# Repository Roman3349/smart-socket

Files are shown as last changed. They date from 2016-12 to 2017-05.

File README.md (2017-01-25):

# Smart socket



The IQRF project to switching mains voltage.

## License
This project is licensed under the GPLv3 license:

 > Copyright (C) 2017 Roman Ondráček
 >
 > This program is free software: you can redistribute it and/or modify
 > it under the terms of the GNU General Public License as published by
 > the Free Software Foundation, either version 3 of the License, or
 > (at your option) any later version.
 > 
 > This program is distributed in the hope that it will be useful,
 > but WITHOUT ANY WARRANTY; without even the implied warranty of
 > MERCHANTABILITY or FITNESS FOR A PARTICULAR PURPOSE.  See the
 > GNU General Public License for more details.
 >
 > You should have received a copy of the GNU General Public License
 > along with this program.  If not, see <http://www.gnu.org/licenses/>.

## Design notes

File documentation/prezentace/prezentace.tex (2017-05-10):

\documentclass[11pt]{beamer}
% Nastavení znakové sady Unicode
\usepackage{cmap}
\usetheme{Madrid}
\usepackage[utf8]{inputenc}
\usepackage[czech]{babel}
\usepackage[T1]{fontenc}
\usepackage{graphicx}
\usepackage{url}
\usepackage{hyperref}
\author[Roman Ondráček]{Roman Ondráček (Gymnázium Boskovice)}
\title[Dálkové ovládání domácích spotřebičů]{Dálkové ovládání domácích spotřebičů mobilním telefonem}
\setbeamercovered{transparent}
%\setbeamertemplate{navigation symbols}{}
\titlegraphic{}
\institute[]{Školitel: prof. Ing. Václav Říčný, CSc. (FEKT VUT)}
\date{\today}
%\subject{}
\begin{document}

\begin{frame}
\titlepage
\end{frame}

\begin{frame}{Obsah}
\tableofcontents
\end{frame}

\section{Co bylo cílem projektu}

\begin{frame}{Co bylo cílem projektu}
V~posledních létech je ve středu pozornosti tzv. Internet věcí a chytrá domácnost. \\[4mm]
Cílem projektu bylo navrhnout a sestavit chytrou zásuvku, která se ovládá pomocí SMS a která může spínat odporovou zátěž až 10~A.
\end{frame}

\section{Použité technologie}

\begin{frame}{Použité technologie}
  \begin{exampleblock}{Brána}
    \begin{itemize}
      \item Raspberry Pi 2
      \item Raspbian (Debian)
      \item Skriptovací jazyk Python 3
      \item USB GSM modem
      \item Bezdrátový modul IQRF DCTR-72DAT
      \item IQRF OS 3.08, IQRF DPA 2.x
    \end{itemize}
  \end{exampleblock}
  \begin{alertblock}{Chytrá zásuvka}
    \begin{itemize}
      \item Bezdrátový modul IQRF DCTR-72DAT
      \item IQRF OS 3.08, IQRF DPA 2.x
      \item Programovací jazyk C
    \end{itemize}
  \end{alertblock}
\end{frame}

\subsection{Bezdrátový modul IQRF}

\begin{frame}{Bezdrátový modul IQRF}
  Použil jsem bezdrátový modul IQRF DCTR-72DAT, který vyvíjí česká firma MICRORISC s.r.o., která sídlí v Jičíně.
  \begin{exampleblock}{Výhody}
    \begin{itemize}
      \item Malé rozměry.
      \item Zabezpečený přenos dat.
      \item Dobrá technická podpora.
      \item SDK pro mnoho platforem.
      \item V IQRF OS 4.0 je provoz šifrován pomocí šifry AES-128.
    \end{itemize}
  \end{exampleblock}
  \begin{alertblock}{Nevýhody}
    \begin{itemize}
      \item Vyšší cena.
    \end{itemize}
  \end{alertblock}
\end{frame}

\subsection{Komunikace}

\begin{frame}{Blokové schéma komunikace}
  \begin{center}
    
  \end{center}
\end{frame}

%\section{Bloková schémata}
%
%\begin{frame}{Bloková schémata}
%  \begin{center}
%    \minipage{0.50\textwidth}
%      \begin{figure}
%        \includegraphics[width = \textwidth]{../img/blokove-schema/brana.pdf}
%        \caption{Brána}
%      \end{figure}
%    \endminipage
%    \minipage{0.50\textwidth}
%      \begin{figure}
%        \includegraphics[width = \textwidth]{../img/blokove-schema/zasuvka.pdf}
%        \caption{Chytrá zásuvka}
%      \end{figure}
%    \endminipage
%  \end{center}
%\end{frame}

\section{Fotografie}

\begin{frame}{Fotografie}
  \begin{center}
    \minipage{0.50\textwidth}
      \begin{figure}
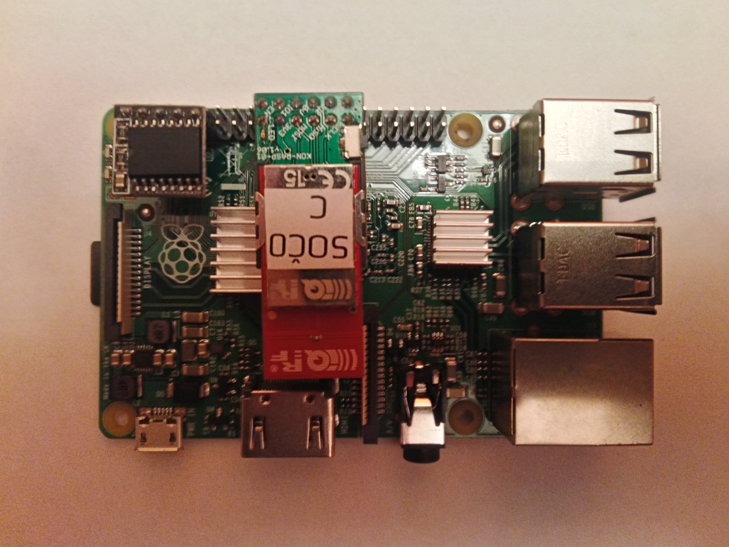
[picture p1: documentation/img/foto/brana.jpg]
        
        \caption{Brána}
      \end{figure}
    \endminipage
    \minipage{0.50\textwidth}
      \begin{figure}
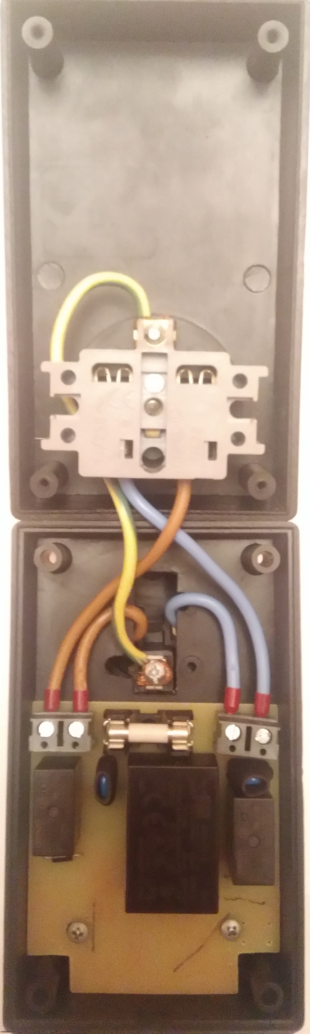
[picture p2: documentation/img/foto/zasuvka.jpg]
        
        \caption{Chytrá zásuvka}
      \end{figure}
    \endminipage
  \end{center}
\end{frame}

\section{Výhody a nevýhody řešení}

\begin{frame}{Výhody a nevýhody řešení}
  \begin{exampleblock}{Výhody}
    \begin{itemize}
      \item Projekt je open-source a je vytvořen pomocí open-source nebo freeware nástrojů.
      \item Chytrá zásuvka je provozně bezpečnější než většina konkurenčních zařízení, protože spíná obě zdířky zásuvky.
      \item Díky univerzálnosti a stavebnicovému řešení lze systém dobře rozšiřovat i o další funkce.
    \end{itemize}
  \end{exampleblock}
  \begin{alertblock}{Nevýhody}
    \begin{itemize}
      \item Vyšší cena.
    \end{itemize}
  \end{alertblock}
\end{frame}

\section{Živá ukázka}
\begin{frame}{Živá ukázka}
  \begin{center}
    \huge{\textit{Pravděpodobně} živá ukázka} \\
    \vspace{8mm}
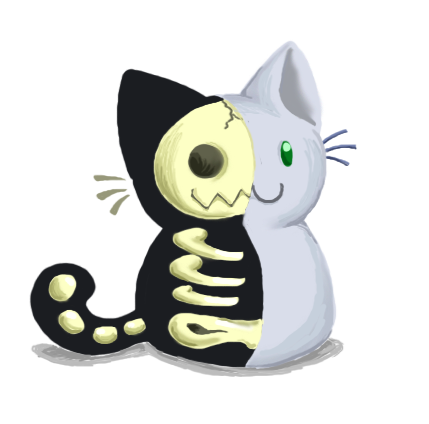
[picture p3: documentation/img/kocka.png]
    
    \vspace{8mm}
  \end{center}
  \small{Autor obrázku: Ketrina Yim (draguunthor.deviantart.com)}
\end{frame}

\section{Cíle do budoucna}

\begin{frame}{Cíle do budoucna}
  \begin{itemize}
    \item Doplnění měření spotřeby připojeného spotřebiče.
    \item Doplnění senzorů (např. pro měření teploty, vlhkosti).
    \item Doplnění možnosti ovládat zařízení přes Internet.
    \item Vytvoření mobilní aplikace pro Android, která by zjednodušila ovládání.
  \end{itemize}
\end{frame}

\begin{frame}
  \begin{center}
    \begin{huge}
    Děkuji za pozornost. \\[8mm]
    \end{huge}
    \large{Dotazy?}\\[16mm]
    \textbf{Zdrojové kódy:} \\
    \url{https://github.com/Roman3349/rpi-gw} \\
    \url{https://github.com/Roman3349/smart-socket} \\[16mm]
  \end{center}
  Zdroje obrázků:
  \begin{itemize}
    \item[] \hspace{-8mm} \tiny{\textbf{Schrödingerova kočka:} \url{http://draguunthor.deviantart.com/art/Schrodinger-s-Cat-163302750}}
  \end{itemize}
\end{frame}

\end{document}

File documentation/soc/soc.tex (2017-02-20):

\documentclass[12pt,a4paper,oneside]{article}
% Nastavení znakové sady Unicode
\usepackage{cmap}
\usepackage[a4paper,left=35mm,right=30mm,top=30mm,bottom=30mm]{geometry}
\usepackage[czech]{babel}
\usepackage[utf8]{inputenc}
\usepackage[T1]{fontenc}
\usepackage[dvipsnames]{xcolor}
\usepackage{float}
\usepackage{graphicx}
\usepackage{hyperref}
\usepackage{index}
\usepackage{listings}
\usepackage{url}
\usepackage{enumitem}
\input{yaml.tex}
\setlist{nolistsep}
\author{Roman Ondráček}
\title{Dálkové ovládání domácích spotřebičů mobilním telefonem}
% Vytvoření seznamu použitých zkratek
\newindex{zkr}{zdx}{znd}{Seznam použitých zkratek}
\lstset{
  inputencoding=utf8
}
\begin{document}
% Řádkování 1,5
\renewcommand{\baselinestretch}{1.5}
% Vynechání číslování
\pagestyle{empty}
\begin{center}
\large \textbf{STŘEDOŠKOLSKÁ ODBORNÁ ČINNOST} \\

\vspace{48mm}
% Český název
\huge \textbf{Dálkové ovládání domácích spotřebičů mobilním telefonem} \\

\vspace{64mm}
\end{center}

\begin{tabbing}
% Nastavení zarážek
\hspace{4mm} \= \hspace{24mm} \= \kill
\> \large \textbf{Autor:}  \> \large{Roman Ondráček}                                    \\[4mm]
\> \large \textbf{Škola:}  \> \large{Gymnázium Boskovice, příspěvková organizace}       \\[4mm]
\> \large \textbf{Kraj:}   \> \large{Jihomoravský}                                      \\[4mm]
\> \large \textbf{Obor:}   \> \large{10. Elektrotechnika, elektronika a telekomunikace} \\[24mm]
\> \large \textbf{Boskovice 2017}
\end{tabbing}

\newpage
% Zakázání číslování
\pagestyle{empty}
\begin{center}
\large \textbf{STŘEDOŠKOLSKÁ ODBORNÁ ČINNOST} \\

\vspace{48mm}
% Český název
\huge \textbf{Dálkové ovládání domácích spotřebičů mobilním telefonem} \\
\vspace{24mm}
% Anglický název
\huge \textbf{The remote control of home appliances via a mobile phone} \\

\vspace{24mm}
\end{center}

\begin{tabbing}
% Nastavení zarážek
\hspace{4mm} \= \hspace{24mm} \= \kill
\> \large \textbf{Autor:}     \> \large{Roman Ondráček}                                    \\[4mm]
\> \large \textbf{Škola:}     \> \large{Gymnázium Boskovice, příspěvková organizace}       \\[4mm]
\> \large \textbf{Kraj:}      \> \large{Jihomoravský}                                      \\[4mm]
\> \large \textbf{Školitel:}  \> \large{prof. Ing. Václav Říčný, CSc.}                     \\[4mm]
\> \large \textbf{Obor:}      \> \large{10. Elektrotechnika, elektronika a telekomunikace} \\[16mm]
\> \large \textbf{Boskovice 2017}
\end{tabbing}

\normalsize

\newpage

~ \vspace{128mm}

\section*{Prohlášení}

Prohlašuji, že svou práci na téma Dálkové ovládání domácích spotřebičů mobilním telefonem jsem vypracoval samostatně pod vedením prof. Ing. Václava Říčného, CSc. a s~použitím odborné literatury a dalších informačních zdrojů, které jsou všechny citovány v~práci a uvedeny v~seznamu literatury na konci práce. \\
Dále prohlašuji, že tištěná i elektronická verze práce SOČ jsou shodné a nemám závažný důvod proti zpřístupňování této práce v~souladu se zákonem č.~121/2000 Sb., o~právu autorském, o~právech souvisejících s~právem autorským a změně některých zákonů (autorský zákon) v~platném změní. \\[8mm]
V~Boskovicích dne \today \hspace{24mm} Podpis:

\newpage

~ \vspace{110mm}

\section*{Poděkování}

Děkuji svému školiteli prof. Ing. Václavu Říčnému CSc. za obětavou pomoc a podnětné připomínky, které mi během práce poskytoval. \\
Tato práce byla provedena za finanční podpory Jihomoravského kraje.

\vspace{8mm}
% Loga
\begin{figure}[!htb]
\minipage{0.50\textwidth}
   \\[8mm]
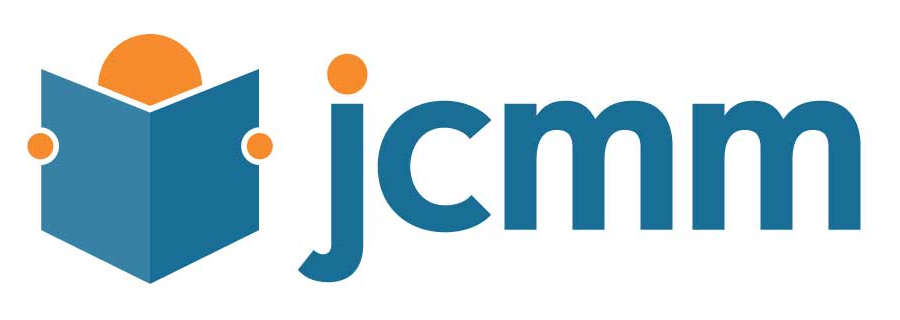
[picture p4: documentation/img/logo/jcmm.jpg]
  
\endminipage
\minipage{0.50\textwidth}
  
\endminipage
\end{figure}

\newpage

\section*{Anotace}

Cílem této práce je navrhnout a sestavit chytrou zásuvku, která se ovládá pomocí SMS a která může spínat odporovou zátěž až 10~A. Součástí mé práce je technická dokumentace výrobku, popis postupu výroby a samotný výrobek.

\subsection*{Klíčová slova}

GSM; SMS; IQRF; relé

\section*{Annotation}

The goal of this work is to design and build a smart power socket, which is controlled by a text message and which can switch resistive loads up to current 10~A. My work includes technical documentation, a description of the manufacturing process and the product itself.

\subsection*{Keywords}

GSM; text message; IQRF; relay

\newpage

% Nastavení číslování od Obsahu
\setcounter{page}{1}

\tableofcontents

\newpage

% Povolení číslování
\pagestyle{plain}

\section*{Úvod}

\addcontentsline{toc}{section}{Úvod}

V~posledních létech je ve středu pozornosti tzv. Internet věcí (IoT\index[zkr]{IoT!Internet of things|textit}) a chytrá domácnost. Na trhu jsou nabízeny chytré zásuvky, které však obvykle ovládány na kratší vzdálenosti a nenabízejí možnost pohodlně a bezpečně je ovládat vzdáleně pomocí mobilního telefonu. \\

Obvykle jsou tyto chytré zásuvky ovládány pomocí komunikace WiFi, která používá kmitočtové pásmo 2,4 GHz. Tato frekvence je hlavně ve městech hodně zarušená, protože se používá i pro přenosy jiných dat\cite{wiki/ism-band}. A proto většinou tyto chytré zásuvky lze ovládat pouze v~místní síti (LAN\index[zkr]{LAN!Local area network|textit}). Tento projekt má tedy umožnit ovládat tyto zásuvky (a tedy i elektrické spotřebiče v~nich zapojené) z~libovolné vzdálenosti. Navržený systém dálkového ovládání pomocí mobilního telefonu by měl, kromě vlastního ovládání, zabezpečit i přenos informace uživateli o~aktuálním stavu zásuvky. Cílem projektu je tedy návrh takové dálkově ovládané chytré zásuvky, její realizace a ověření funkčního vzorku. \\

Většina chytrých zásuvek obsahuje pouze jedno relé\cite{teardown-wemo-switch}, protože musí se povinně spínat fáze (spínání nulového vodiče je nepovinné). To přináší problém, protože například ve Francii, kde se stejně jako v~České republice použita zásuvka typu E\cite{zasuvka-typ-e}, je zdířka fáze umístěna vpravo nikoliv vlevo jako v~České republice\cite{faze-vlevo-nebo-vpravo}. Proto navržené řešení obsahuje i druhé relé pro spínání nulového vodiče. \\

Pro řešení zadání projektu jsem se rozhodl použít technologii IQRF. Je to technologie vyvinutá českou firmou Microrisc s.r.o., která se poměrně často používá ve světě internetu věcí a jiných systémů pro bezdrátový přenos malých objemů dat. Firma dává k~dispozici relativně malé moduly, které je možno integrovat do konkrétních zákaznických řešení.

\newpage

\section{Návrh hardware}

\subsection{Chytrá zásuvka}

Chytrá zásuvka je napájena ze sítě pomocí modulového spínaného zdroje do desky plošných spojů MEAN WELL IRM-02-5, který má výstupní napětí 5~V a maximální výstupní proud je 400~mA. \\

Chytrá zásuvka je řízena bezdrátovým modulem IQRF DCTR-72DAT, který spíná SMD\index[zkr]{SMD!Surface-mounted device|textit} unipolární tranzistory N-MOSFET\index[zkr]{N-MOSFET!N-Channel metal–oxide–semiconductor field-effect transistor|textit} BSS138. Ty spínají které spínají cívky dvou relé (jedno je použito pro spínání fáze a druhé relé je použito pro spínání nulového vodiče) OMRON G5Q-1A4-EU. \\

Při rozepnutí proudu v~cívce relé vzniká vlivem její indukčnosti napěťová špička, která může zničit spínací tranzistor. Proražení tranzistoru lze zabránit diodou paralelně zapojenou k~relé, která při rozepnutí relé uzavře obvod kolem indukčnosti. Použil jsem usměrňovací diodu 1N4007. Abych zabránil jiskření na kontaktech relé, jsem použil varistor MOV\index[zkr]{MOV!Metal Oxide Varistor|textit} SR PASSIVES VAR10-250.

\newpage

\subsubsection{Bezdrátový modul IQRF DCTR-72DAT}

V~chytré zásuvce jsem použil bezdrátový modul IQRF DCTR-72DAT, který rovněž vyrábí česká firma MICRORISC s.r.o., která sídlí v~Jičíně. Plošný spoj modulu má podobné rozměry jako SIM\index[zkr]{SIM!Subscriber identity module|textit} karta, proto je pro jeho připojení s~deskou plošných spojů použit konektor pro SIM karty. \\

\begin{figure}[H]
\centering
\label{fig:iqrf/fotka}
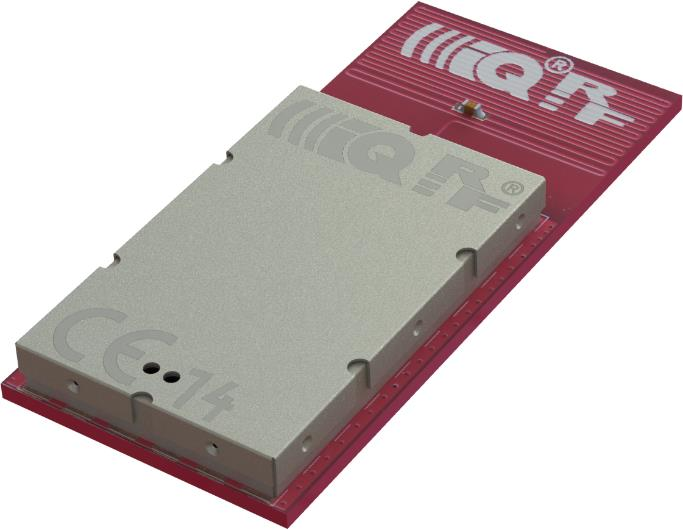
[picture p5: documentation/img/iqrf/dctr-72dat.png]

\caption{Fotografie bezdrátového modulu}
\end{figure}

Modul může vysílat na bezlicenčních pásmech 916~MHz, která je určené pro Ameriku, a 868~MHz, určené pro zbytek světa. Vysílací výkon modulu je 12,5~mW, používá GFSK\index[zkr]{GFSK!Gaussian frequency-shift keying|textit} modulaci. Modul má integrovanou anténu na svém plošném spoji. \\

Pro komunikaci používá tzv. mesh neboli smíšenou topologii. Ta má výhody v~robustnosti a v~absenci centrálního prvku. Její nevýhodou je naopak potřebná ochrana proti zacyklení a nutnost směrování provozu. \\

Modul lze napájet napětím 3,1~V až 5,5~V, protože obsahuje LDO\index[zkr]{LDO!Low-dropout|textit} napěťový stabilizátor Microchip MCP1700T-3002E/TT. Dále modul obsahuje mikrokontrolér Microchip PIC16LF1938. Ten užívá operační systém IQRF OS, který za uživatele zajišťuje komunikaci s~integrovaným obvodem STMicroelectronics Spirit1. Tento obvod řídí bezdrátový datový přenos a má hardwarovou podporu blokové šifry AES-128\index[zkr]{AES!Advanced Encryption Standard|textit}. Operační systém dále ovládá integrované periferie (například digitální teploměr). IQRF DPA\index[zkr]{DPA!Direct Peripheral Access|textit} a uživatelská aplikace. Dále modul obsahuje digitální teploměr Microchip MCP9808E/MC. \\

Microchip PIC16LF1938 je 8-bitový mikrokontrolér s~architekturou PIC, která používá architekturu RISC\index[zkr]{RISC!Reduced instruction set computing|textit}, jenž má omezenou instruktážní sadu a rychlé vykonávání instrukcí. Flash paměť pro program má velikost 28~kB, paměť EEPROM má velikost 256~B a paměť SRAM má velikost 1~kB.

\begin{figure}[H]
\centering
\label{fig:iqrf/zjednodusene-schema}
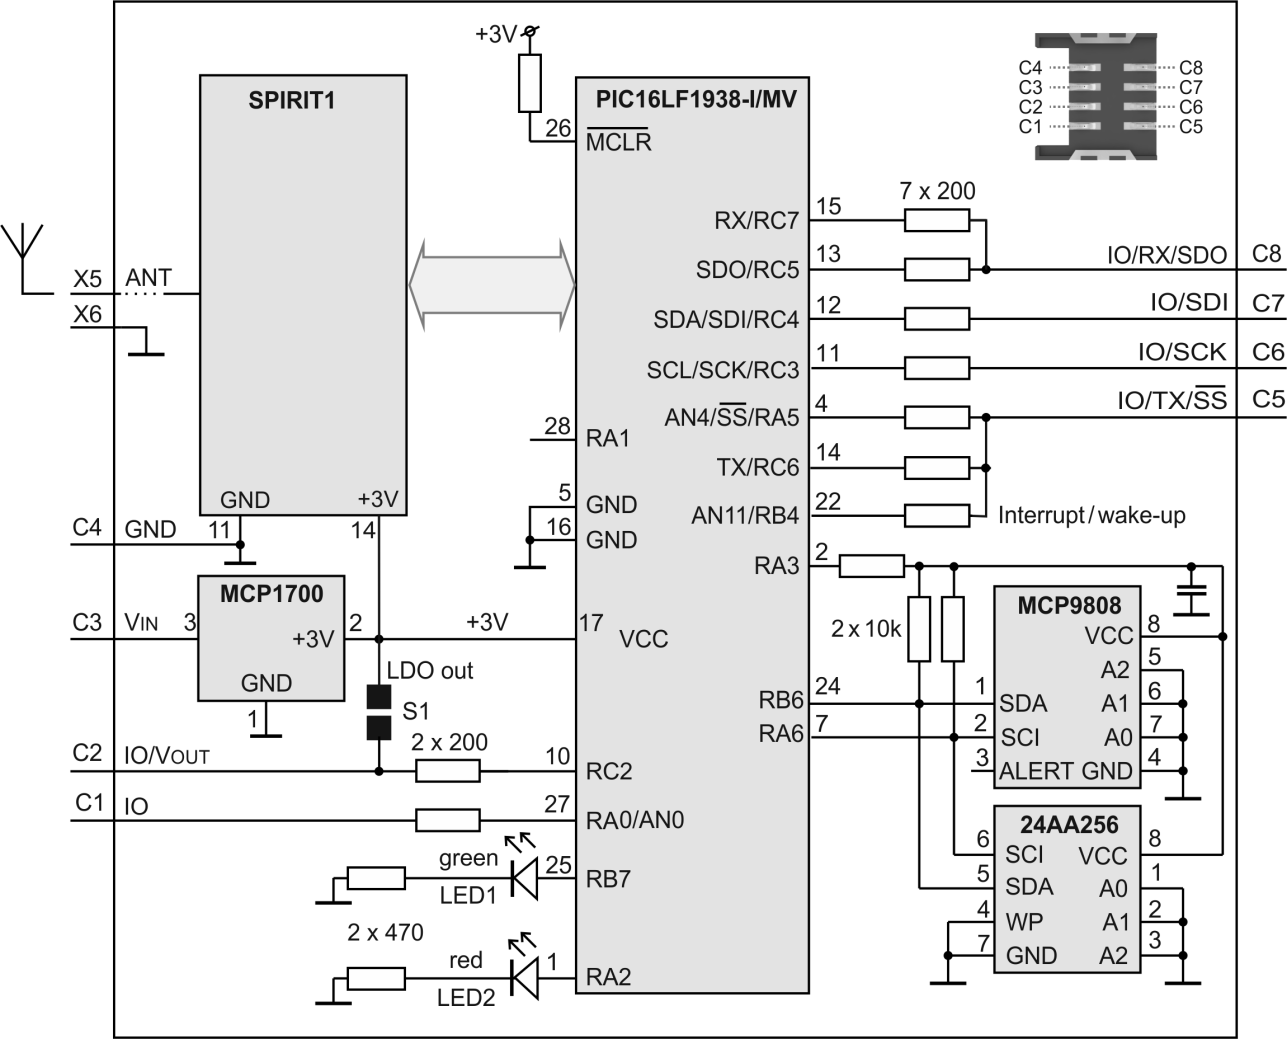
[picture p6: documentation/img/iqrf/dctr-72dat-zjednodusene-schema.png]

\caption{Zjednodušené schéma bezdrátového modulu}
\end{figure}

Přestože je v~integrovaném obvodu řídící radiovou komunikaci hardwarová podpora šifry AES-128, tak podpora této šifry není v~IQRF OS\index[zkr]{OS!Operating system|textit}\index[zkr]{OS!Operační systém|textit} ještě implementována a místo ní se používá upravená bloková šifra XTEA\index[zkr]{XTEA!eXtended Tiny Encryption Algorithm|textit}, která je však méně bezpečná. Bloková šifra AES-128 bude implementovaná v~IQRF OS ve verzi 4.0, která má vyjít v~prvním čtvrtletí roku 2017.

\newpage

\subsubsection{Blokové schéma}

Na obrázku č.~3 se nachází blokové schéma chytré zásuvky, které popisuje její zapojení. Obrázek byl vytvořený v~open-source programu Dia\cite{sw/dia}.

\begin{figure}[H]
\centering
\label{fig:blokove-schema-zasuvky}

\caption{Blokové schéma chytré zásuvky}
\end{figure}

\newpage

\subsubsection{Obvodové schéma}

Na obrázku č.~4 se nachází obvodové schéma chytré zásuvky. Obrázek je vytvořen v~open-source programu KiCad\cite{sw/kicad}.

\begin{figure}[H]
\centering
\label{fig:schematic}

\caption{Obvodové schéma chytré zásuvky}
\end{figure}

\newpage

\subsubsection{Výkres plošného spoje a rozložení součástek}

\begin{figure}[H]
\centering
\label{fig:board}

\caption{Výkres plošného spoje chytré zásuvky}
\end{figure}

\begin{figure}[H]
\centering
\label{fig:components}

\caption{Rozložení součástek na desce plošného spoje chytré zásuvky}
\end{figure}

\newpage

\subsubsection{Rozpiska součástek}

\begin{table}[H]
  \centering
  \begin{tabular}{|l|l|}
    \hline
    \textbf{Značka} & \textbf{Jméno součástky} \\
    \hline
    \hline
    ~ & Krabička COMBIPLAST CP-Z-27/B \\
    \hline
    C1 & Keramický SMD 1206 kondenzátor 100~nF \\
    \hline
    D1, D2 & Dioda 1N4007 \\
    \hline
    F1 & Tavná keramická pojistka 10~A 250~VAC \\
    \hline
    IC1 & Bezdrátový modul IQRF DCTR-72DAT \\
    \hline
    ~ & Konektoru IQRF KON-SIM-01 pro IC1 \\
    \hline
    J1, J2 & Svorkovnice do DPS\index[zkr]{DPS!Deska plošných spojů|textit} DEGSON DG300-7.5-02P \\
    \hline
    Q1, Q2 & N-MOSFET BSS138 \\
    \hline
    R1, R2 & Rezistor SMD 1206 10~k$\Omega$ \\
    \hline
    RL1, RL2 & Relé OMRON G5Q-1A4-EU 5VDC \\
    \hline
    RV1, RV2 & MOV varistor SR PASSIVES VAR10-250 \\
    \hline
    D3, SW1 & Mikrospínač HIGHLY PB6141FL-13 \\
    \hline
    U1 & Spínaný zdroj MEAN WELL IRM-02-5 \\
    \hline
  \end{tabular}
  \caption{Rozpiska součástek chytré zásuvky}\label{table:rozpiska-soucastek}
\end{table}

\newpage

\subsection{Brána}

Pro bránu jsem použil linuxový jednodeskový počítač Raspberry Pi 2 model B. Bezdrátový modul IQRF DCTR-72DAT je k~bráně připojen přes sběrnici SPI\index[zkr]{SPI!Serial Peripheral Interface|textit} pomocí adaptéru IQRF KON-RASP-01. Pro komunikaci s~GSM sítí lze použít USB\index[zkr]{USB!Universal Serial Bus|textit} GSM\index[zkr]{GSM!Global System for Mobile Communications|textit}\index[zkr]{GSM!Groupe SpécialMobile|textit}/3G modem (například Huawei E3131) nebo starší mobilní telefon (například Samsung Star II nebo Samsung Galaxy Gio). Brána se napájí pomocí externího spínaného zdroje s~microUSB konektorem, který má výstupní napětí 5~V a maximální výstupní proud 2~A.

\begin{figure}[H]
\centering
\label{fig:iqrf/fotka-kon-rasp-01}
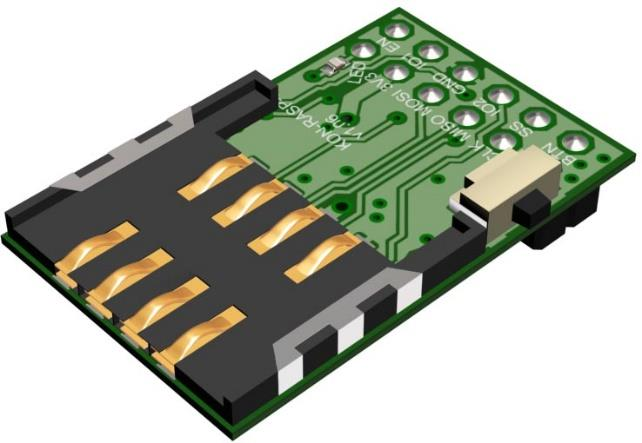
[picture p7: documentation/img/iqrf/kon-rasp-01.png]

\caption{Fotografie adaptéru IQRF KON-RASP-01}
\end{figure}

\begin{figure}[H]
\centering
\label{fig:iqrf/zjednodusene-schema-kon-rasp-01}
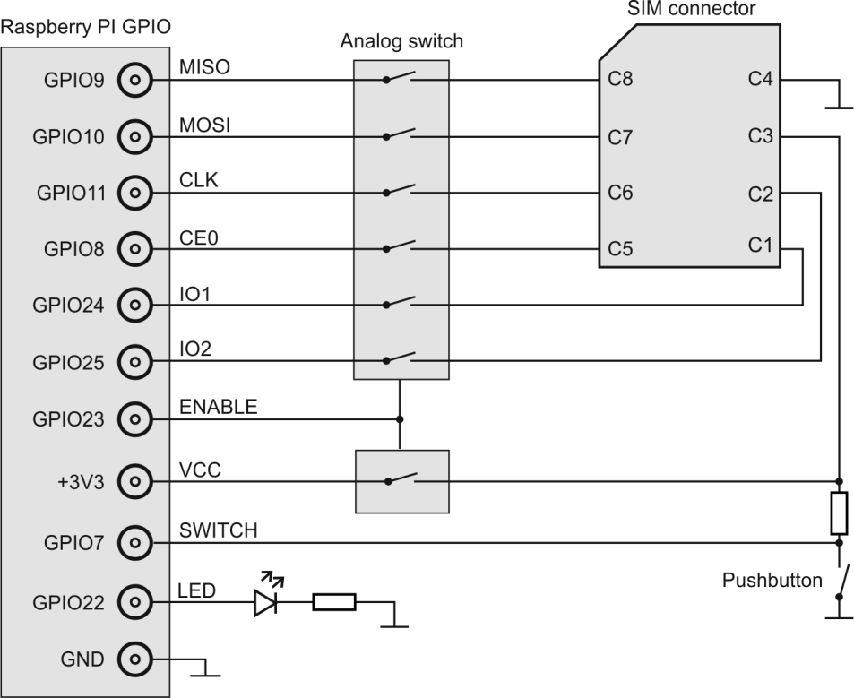
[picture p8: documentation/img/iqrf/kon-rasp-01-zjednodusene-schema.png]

\caption{Zjednodušené schéma adaptéru IQRF KON-RASP-01}
\end{figure}

\subsubsection{Raspberry Pi 2 model B}

Raspberry Pi 2 model B je jednodeskový počítač, který má rozměry podobné kreditní kartě. Tento počítač obsahuje:

\begin{itemize}
  \item čtyřjádrový ARM\index[zkr]{ARM!Acorn RISC Machine|textit}\index[zkr]{ARM!Advanced RISC Machine|textit} Cortex-A7 Broadcom BCM2836,
  \item 1~GB operační paměti RAM\index[zkr]{RAM!Random-access memory|textit},
  \item čtyři USB 2.0 porty
  \item port RJ45 pro 100~Mb síťovou kartu,
  \item slot pro microSD\index[zkr]{SD!Secure Digital|textit} kartu,
  \item HDMI\index[zkr]{HDMI!High-Definition Multimedia Interface|textit} výstup,
  \item 40 GPIO\index[zkr]{GPIO!General-purpose input/output|textit} pinů, na kterých jsou vyvedeny sběrnice SPI\index[zkr]{SPI!Serial Peripheral Interface|textit}, I2C\index[zkr]{I2C!Inter-Integrated Circuit|textit}, USART\index[zkr]{USART!Universal Synchronous / Asynchronous Receiver and Transmitter|textit}.
\end{itemize}

\begin{figure}[H]
\centering
\label{fig:foto/rpi2}
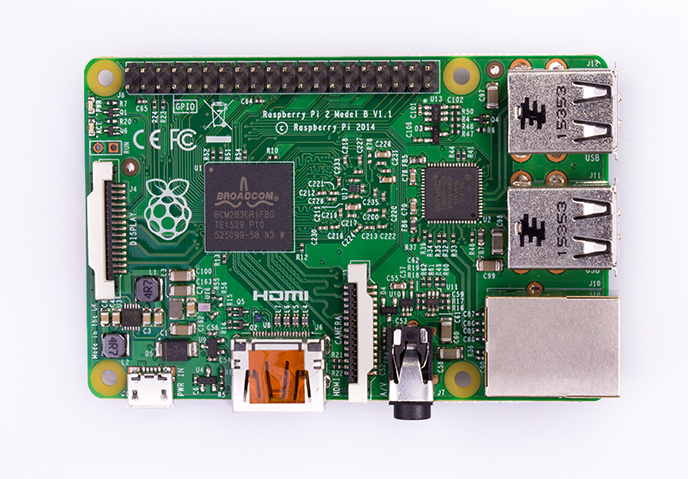
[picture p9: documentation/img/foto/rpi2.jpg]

\caption{Fotografie jednodeskového počítače Raspberry Pi 2 model B}
\end{figure}

\newpage

\subsubsection{Blokové schéma brány}

Na obrázku č.~7 se nachází blokové schéma brány, které popisuje její zapojení. Obrázek byl vytvořený v~open-source programu Dia\cite{sw/dia}.

\begin{figure}[H]
\centering
\label{fig:blokove-schema-zasuvky}

\caption{Blokové schéma brány}
\end{figure}

\subsubsection{Rozpiska součástek}

\begin{table}[H]
  \centering
  \begin{tabular}{|l|l|}
    \hline
    %\textbf{Značka} &
    \textbf{Jméno součástky} \\
    \hline
    \hline
    %~ &
    Raspberry Pi 2 model B \\
    \hline
    %~ &
    adaptér IQRF KON-RASP-01 \\
    \hline
    %~ &
    bezdrátový modul IQRF DCTR-72DAT \\
    \hline
    %~ & ~ \\
    %\hline
  \end{tabular}
  \caption{Rozpiska součástek brány}\label{table:rozpiska-soucastek/brana}
\end{table}

\newpage

\section{Návrh software}

\subsection{Komunikace}

Mobilní telefon komunikuje s~bránou pomocí zpráv SMS\index[zkr]{SMS!Short message service|textit}. Brána SMS zprávu zpracuje a pokud je zpráva validní, tak pošle požadavek na chytrou zásuvku přes bezdrátový modul IQRF. Chytrá zásuvka vrátí svůj stav bráně, která poté informuje uživatele, zda byla akce úspěšná.

\begin{figure}[H]
\centering
\label{fig:iqrf/zjednodusene-schema}

\caption{Zjednodušené schéma komunikace}
\end{figure}

\newpage

\subsection{Chytrá zásuvka}

Software chytré zásuvky je psán v~programovacím jazyce C. Software byl napsán ve vývojovém prostředím IQRF IDE\cite{iqrf/ide}\index[zkr]{IDE!Integrated Development Environment|textit}.

\subsubsection{Vývojové prostředí IQRF IDE}

IQRF IDE\cite{iqrf/ide} je zdarma stažitelné vývojové prostředí, které je určené pro vývoj aplikací pro bezdrátové moduly IQRF. Toto vývojové prostředí je pouze pro operační systém Microsoft Windows. Uživatelé operačního systému Apple OS X nebo libovolné linuxové distribuce nemohou vyvíjet software pro tyto bezdrátové moduly. IQRF IDE používá kompilátor CC5X C Compiler\cite{cc5x-compiler}.

\begin{figure}[H]
\centering
\label{fig:iqrf/ide}
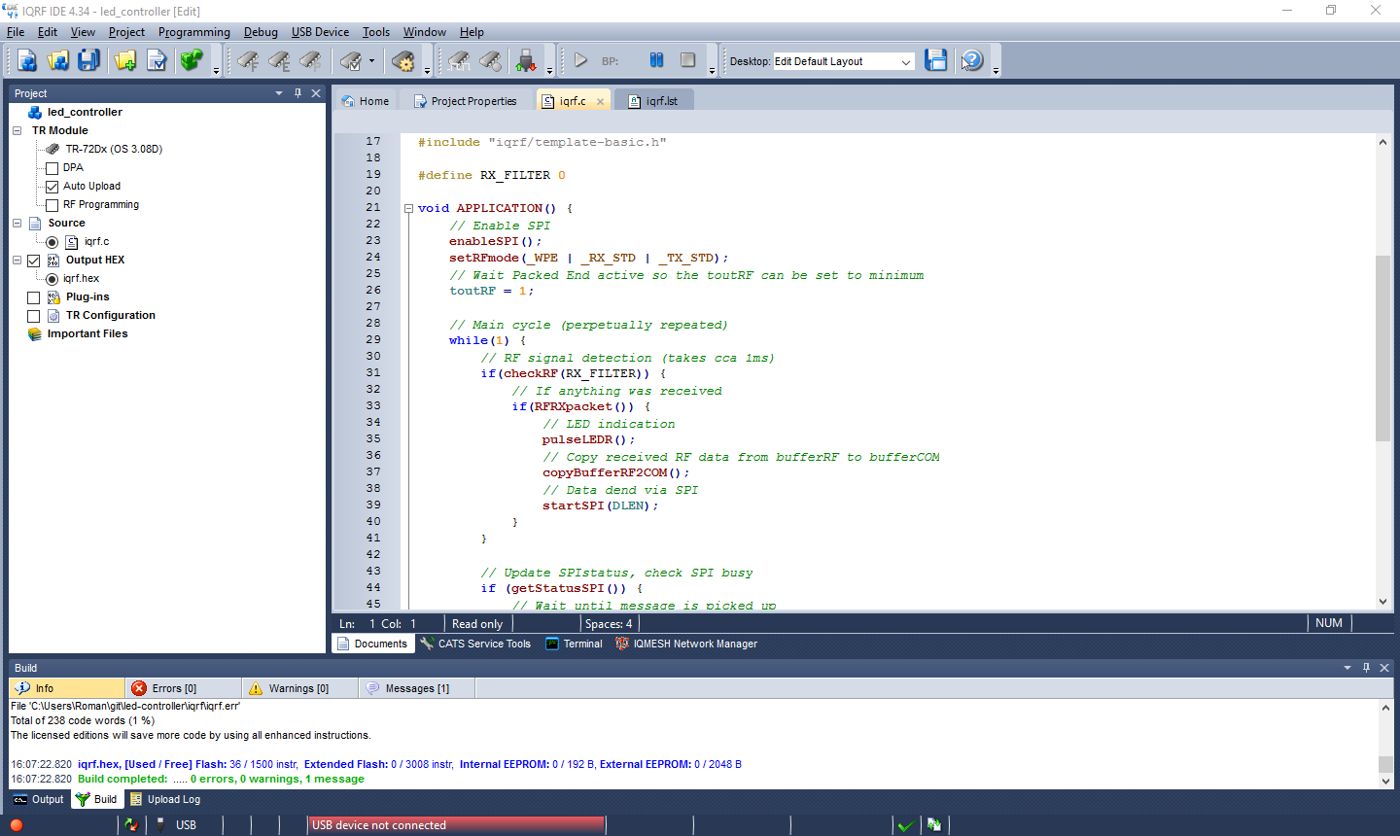
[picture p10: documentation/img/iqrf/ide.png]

\caption{Vývojové prostředí IQRF IDE}
\end{figure}

\newpage

\subsubsection{Operační systém IQRF OS}

IQRF OS\cite{iqrf/os} je operační systém určený pro bezdrátové moduly IQRF, pomocí kterého může uživatel jednoduše:

\begin{itemize}
  \item ovládat rádiovou komunikaci,
  \item ovládat komunikaci v~mesh síti,
  \item komunikovat s~periferiemi přes sběrnice SPI, USART, I2C,
  \item pracovat s~pamětmi RAM\index[zkr]{RAM!Random-access memory|textit}, EEPROM\index[zkr]{EEPROM!Electrically Erasable Programmable Read-Only Memory|textit},
  \item inicializovat GPIO,
  \item spínat GPIO,
  \item číst logické hodnoty z~GPIO,
  \item spínat integrované LED\index[zkr]{LED!Light-Emitting Diode|textit} diody,
  \item generovat PWM\index[zkr]{PWM!Pulse Width Modulation|textit} na výstupním pinu,
  \item číst hodnoty z~analogově digitálního převodníku,
  \item číst teplotu z~integrovaného teplotního senzoru.
\end{itemize}

\begin{figure}[H]
\centering
\label{fig:foto/iqrf-os}
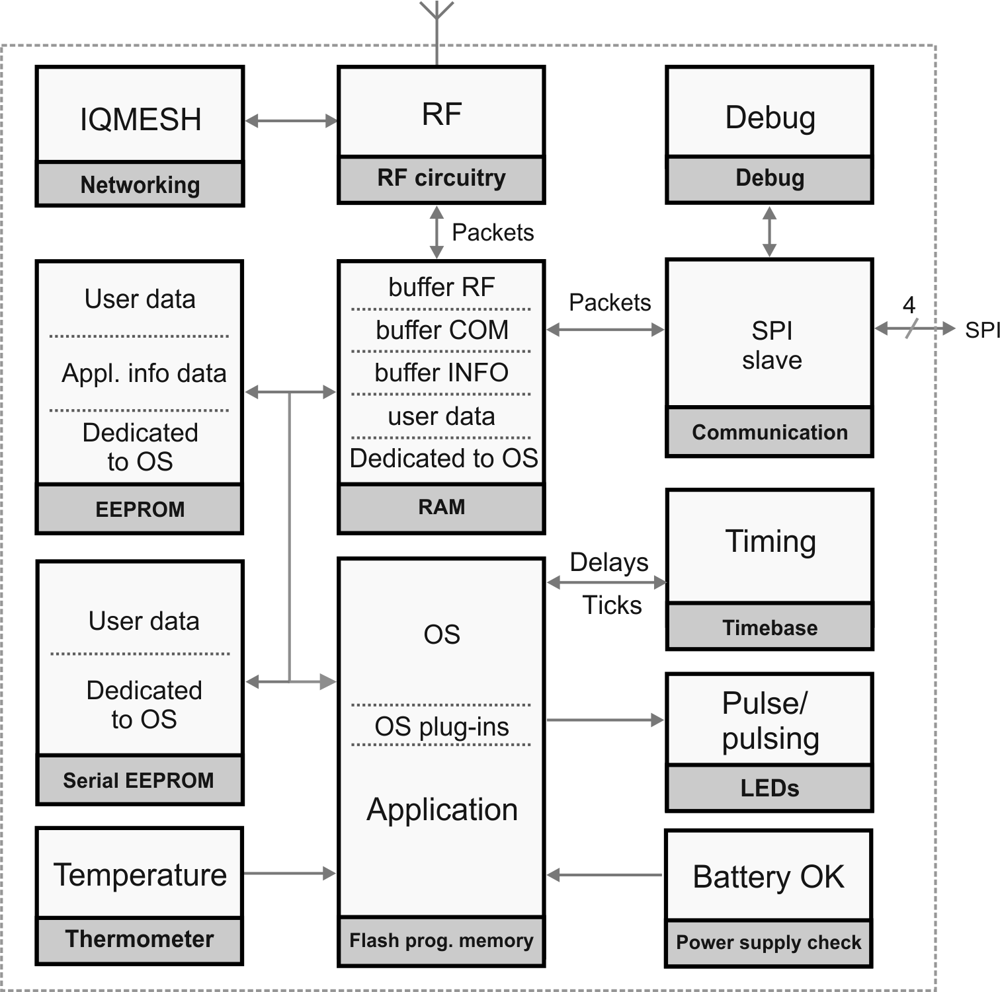
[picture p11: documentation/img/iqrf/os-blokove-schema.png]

\caption{Blokové schéma operačního systému IQRF OS}
\end{figure}

\newpage

\subsubsection{Protokol IQRF DPA}

IQRF DPA\cite{iqrf/dpa} je vrstva nad IQRF OS, která se stará o~protokol komunikace IQRF bezdrátových modulů. IQRF DPA má pevně danou strukturu paketů, která je uvedena v~tabulce č.~3. Centrální prvek v~IQRF mesh síti se jmenuje koordinátor, který je umístěn v~bráně. Koordinátor má se své paměti EEPROM uložené informace o~dalších bezdrátových modulech, se kterými má komunikovat. Pokud koordinátor přijme data od bezdrátového modulu, jehož informace nemá uložené v~EEPROM paměti, pak data ignoruje.

\begin{table}[H]
\centering
\begin{tabular}{|c|c|c|c|c|}
\hline
NADR & PNUM & PCMD & HWPID & DATA \\
\hline
siťová adresa & číslo periferie & příkaz & HWP\index[zkr]{HWP!Hardware profile|textit} identifikátor & data \\
\hline
\end{tabular}
\caption{Schéma paketu IQRF DPA}\label{table:iqrf/dpa}
\end{table}

\newpage

\subsection{Brána}

V~bráně běží linuxová distribuce Raspbian, což je speciálně upravená linuxová distribuce pro jednodeskový počítač Raspberry Pi. Tato linuxová distribuce je odvozená od linuxové distribuce Debian, která je jedna z~nejpoužívanějších linuxových distribucích. Software brány je psán v~skriptovacím jazyce Python. Abych si byl jistý, že všechny komponenty softwaru brány fungují, vytvořil jsem pomocí nástroje unittest psal unit testy, které testují důležité komponenty (například čtení konfiguračního souboru). \\

Konfigurační soubor softwaru brány je psán v~datovém formátu YAML\index[zkr]{YAML!YAML Ain't Markup Language|textit}. V~dalším odstavci je uveden ukázkový konfigurační soubor.

\begin{lstlisting}[language=yaml, numbers=left]
  gsm:
    enabled: true
    interface: uart
    interfaces:
      uart:
        port: "/dev/ttyUSB0"
        baudRate: 9600
    pin: false

  iqrf:
    enabled: true
    interface: spi
    interfaces:
      spi:
        port: "/dev/spidev0.0"
      cdc:
        port: "/dev/ttyACM0"
\end{lstlisting}

\newpage

\subsubsection{AT příkazy}

AT příkazy jsou příkazy, které se používají pro komunikaci s~GSM modemem. Dříve se AT příkazům říkalo Hayesovy příkazy (vymyslel je Dennis Hayes pro svůj Hayes Smartmodem 300). Pojmenování AT příkazy vzniklo podle slova \textbf{AT}tention, což v~češtině znamená pozor, upozornit. \\

Základní AT příkaz je příkaz \textit{AT}, který odpoví OK, pokud je vše v~pořádku. Příkaz \textit{ATI} vypisuje informace o~modemu (například výrobce a model). Pomocí příkazu \textit{AT+CMGF=1} lze nastavit textový ASCII\index[zkr]{ASCII!American Standard Code for Information Interchange|textit} přenos dat. \\

Pokud je SIM karta chráněna PIN kódem, pak je možno ji odemknout pomocí příkazu \textit{AT+CPIN=PIN-SIM-KARTY} a poté pomocí příkazu \textit{AT+CPIN?} ověřit, zda byl zadán správný PIN kód. \\

Pomocí příkazu \textit{AT+CMGL=”ALL”} jsou každou sekundu přečteny všechny SMS zprávy, které jsou uloženy na SIM kartě. Odpověď vypadá takto:

\textit{+CMGL: číslo SMS zprávy,"stav zprávy (přečteno/nepřečteno)","telefonní číslo odesílatele",,"datum a čas přijetí SMS zprávy" \\ Text \\ OK}.
Pomocí příkazu \textit{AT+CMGS="telefonní číslo příjemce" \\ Text <26>\footnote{<26> zastupuje ASCII znak Substitute}} se pak odešle SMS zpráva.

Pomocí příkazu \textit{ATD+420123456789;} se \uv{vytočí} telefonní číslo +420123456789. Následně je pomocí příkazu \textit{AT+CHUP} ukončeno spojení.

\begin{table}[H]
  \centering
  \begin{tabular}{|l|l|}
    \hline
    \textbf{Příkaz} & \textbf{Popis} \\
    \hline
    \hline
    AT & Základní AT příkaz \\
    \hline
    ATI & Vypíše informace o~modemu \\
    \hline
    AT+CPIN=1234 & Odemkne SIM kartu pomocí PINu 1234 \\
    \hline
    AT+CPIN? & Odpoví, jestliže je PIN v~pořádku \\
    \hline
    AT+CMGF=1 & Nastavení textového ASCII přenosus dat \\
    \hline
    AT+CMGL=”ALL” & Přečte všechny SMS zprávy \\
    \hline
    AT+CMGS="telefonní číslo příjemce" & Odeslání SMS zprávy \\
    \hline
    ATD+420123456789; & Vytočí číslo +420123456789 \\
    \hline
    AT+CHUP & Zavěšení hovoru (spojení) \\
    \hline
  \end{tabular}
  \caption{Seznam použitých AT příkazů}\label{table:at-prikazy}
\end{table}

\newpage

\section{Technické parametry}

\subsection{Chytrá zásuvka}

\begin{table}[H]
  \centering
  \begin{tabular}{lr}
    \hline
    \textbf{Technické parametry} & ~ \\
    \hline
    \hline
    \textbf{Rozměry} & 7$\times$12$\times$4,5~cm \\
    \hline
    \textbf{Elektrické parametry} \\
    \hline
    \hline
    \textbf{Napájecí napětí} & 90~V až 250~V AC\index[zkr]{AC!Alternating current|textit} \\
    \textbf{Typická spotřeba} & méně než 0,5~W \\
    \textbf{Maximální spínatelný proud} & 10~A \\
    \hline
    \textbf{Ostatní parametry} \\
    \hline
    \hline
    \textbf{Přenos dat} & bezdrátově na frekvenci 868~MHz \\
    \textbf{Protokol} & IQRF DPA \\
  \end{tabular}
  \caption{Parametry chytré zásuvky}\label{table:parametry/chytra-zasuvka}
\end{table}

\subsection{Brána}

\begin{table}[H]
  \centering
  \begin{tabular}{lr}
    \hline
    \textbf{Technické parametry} & ~ \\
    \hline
    \hline
    \textbf{Rozměry} & 7$\times$12$\times$4,5~cm \\
    \hline
    \textbf{Elektrické parametry} \\
    \hline
    \hline
    \textbf{Napájecí napětí} & 5~V DC\index[zkr]{DC!Direct current|textit} \\
    \textbf{Typická spotřeba} & 6~W \\
  \end{tabular}
  \caption{Parametry brány}\label{table:parametry/zbrana}
\end{table}

\newpage

\section*{Závěr}

\addcontentsline{toc}{section}{Závěr}

Navržený systém dálkového ovládání elektrických spotřebičů byl navržen a realizován ve formě funkčního vzorku. Na obrázcích č.~14 a 15 jsou fotografie funkčního vzorku chytré zásuvky a brány. Funkce chytré zásuvky i celého systému jejího dálkového ovládání pomocí GSM komunikace z~mobilního telefonu vzdáleného uživatele byla ověřena a shledána plně funkční. Výsledkem tohoto projektu je tedy plně funkční chytrá zásuvka, která nejenže splňuje všechny požadavky zadání, ale v~mnoha směrech je i rozšiřuje – například o~zpětný přenos SMS informací vzdálenému uživateli o~okamžitém stavu sepnutí/vypnutí zásuvky. Vzhledem k~charakteru a univerzalitě řešení by systém v~budoucnosti mohl umožnit i zpětný přenos dalších SMS informací (např. teplota v~objektu) nebo ovládání přes Internet.

\begin{figure}[H]
\centering
\label{fig:foto/brana}

\caption{Fotografie funkčního vzorku brány}
\end{figure}

\begin{figure}[H]
\centering
\label{fig:foto/brana}

\caption{Fotografie funkčního vzorku chytré zásuvky}
\end{figure}

\newpage

\printindex[zkr]

\addcontentsline{toc}{section}{Seznam použitých zkratek}

\newpage

\begin{thebibliography}{99}

\addcontentsline{toc}{section}{Seznam použité literatury}

\bibitem{wiki/ism-band}
Wikipedia. ISM\index[zkr]{ISM!Industrial, Scientific and Medical|textit} Band \emph{Wikipedia} [online]. [cit. 2016-01-08]. \\ Dostupné z: \url{https://en.wikipedia.org/wiki/ISM\_band}

\bibitem{wiki/hayes-command-set}
Wikipedia. Hayes command set \emph{Wikipedia} [online]. [cit. 2016-01-08]. \\ Dostupné z: \url{https://en.wikipedia.org/wiki/Hayes\_command\_set}

\bibitem{iqrf/ide}
MICRORISC. IQRF IDE \emph{IQRF} [online]. Jičín, 2016 [cit. 2017-01-09]. \\ Dostupné z: \url{http://iqrf.org/technology/iqrf-ide}

\bibitem{iqrf/os}
MICRORISC. Operating system \emph{IQRF} [online]. Jičín, 2016 [cit. 2017-01-09]. \\ Dostupné z: \url{http://iqrf.org/technology/operating-system}

\bibitem{iqrf/os/guide}
MICRORISC. IQRF OS v3.08D User's guide for TR-7xD \emph{IQRF} [online]. Jičín, 2016 [cit. 2017-01-29]. \\ Dostupné z: \url{http://www.iqrf.org/weben/downloads.php?id=155}

\bibitem{iqrf/dpa}
MICRORISC. DPA \emph{IQRF} [online]. Jičín, 2016 [cit. 2017-01-09]. \\ Dostupné z: \url{http://iqrf.org/technology/dpa}

\bibitem{iqrf/dctr-72d-datasheet}
MICRORISC. Datasheet (DC)TR-72D \emph{IQRF} [online]. Jičín, 2016 [cit. 2017-01-09]. \\ Dostupné z: \url{http://iqrf.org/weben/downloads.php?id=337}

\bibitem{iqrf/kon-rasp-01-datasheet}
MICRORISC. User's guide KON-RASP-01 \emph{IQRF} [online]. Jičín, 2016 [cit. 2017-01-23]. \\ Dostupné z: \url{http://www.iqrf.org/weben/downloads.php?id=412}

\bibitem{microchip/pic16f1938}
MICROCHIP. PIC16F1938 \emph{PIC16F1938} [online]. 2017 [cit. 2017-01-29]. \\ Dostupné z: \url{http://www.microchip.com/wwwproducts/en/PIC16F1938}

\bibitem{robodoupe-mosfet-a-rele}
Jiri Bezstarosti. Tranzistor jako spínač \emph{Robodoupě} [online]. 2012 [cit. 2017-01-09]. \\ Dostupné z: \url{http://robodoupe.cz/2012/tranzistor-jako-spinac/}

\bibitem{faze-vlevo-nebo-vpravo}
Jaroslav Borovec. Fáze vlevo nebo vpravo, v~čem tkví nebezpečí? \emph{Eletrika.cz} [online]. 2009 [cit. 2017-01-09]. \\ Dostupné z: \url{http://elektrika.cz/clanky/faze-vlevo-nebo-vpravo-v-cem-tkvi-nebezpeci}

\bibitem{zasuvka-typ-e}
Oldřich Mrázek. Přehled zásuvek používaných ve světě - Typ E \emph{HW Server} [online]. 2009 [cit. 2017-01-09]. \\ Dostupné z: \url{http://zasuvky.hw.cz/index2.php#E}

\bibitem{teardown-wemo-switch}
Brian Dipert. Teardown: WeMo Switch is highly integrated \emph{EDN} [online]. 2015 [cit. 2017-01-09]. \\ Dostupné z: \url{http://www.edn.com/design/consumer/4440797/Teardown--WeMo-Switch-is-highly-integrated}

\bibitem{sw/dia}
Dia \emph{Dia} [online]. [cit. 2017-01-19]. \\ Dostupné z: \url{https://wiki.gnome.org/Apps/Dia/}

\bibitem{sw/kicad}
KiCad EDA\index[zkr]{EDA!Electronic design automation|textit} \emph{KiCad EDA} [online]. [cit. 2017-01-19]. \\ Dostupné z: \url{http://kicad-pcb.org/}

\bibitem{cc5x-compiler}
B Knudsen Data. CC5X C Compiler \emph{CC5X} [online]. Norsko, 2016 [cit. 2017-01-29]. \\ Dostupné z: \url{http://www.bknd.com/cc5x/}

\end{thebibliography}

\newpage

\listoffigures

\addcontentsline{toc}{section}{Seznam obrázků}

\listoftables

\addcontentsline{toc}{section}{Seznam tabulek}

\end{document}

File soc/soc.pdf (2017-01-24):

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

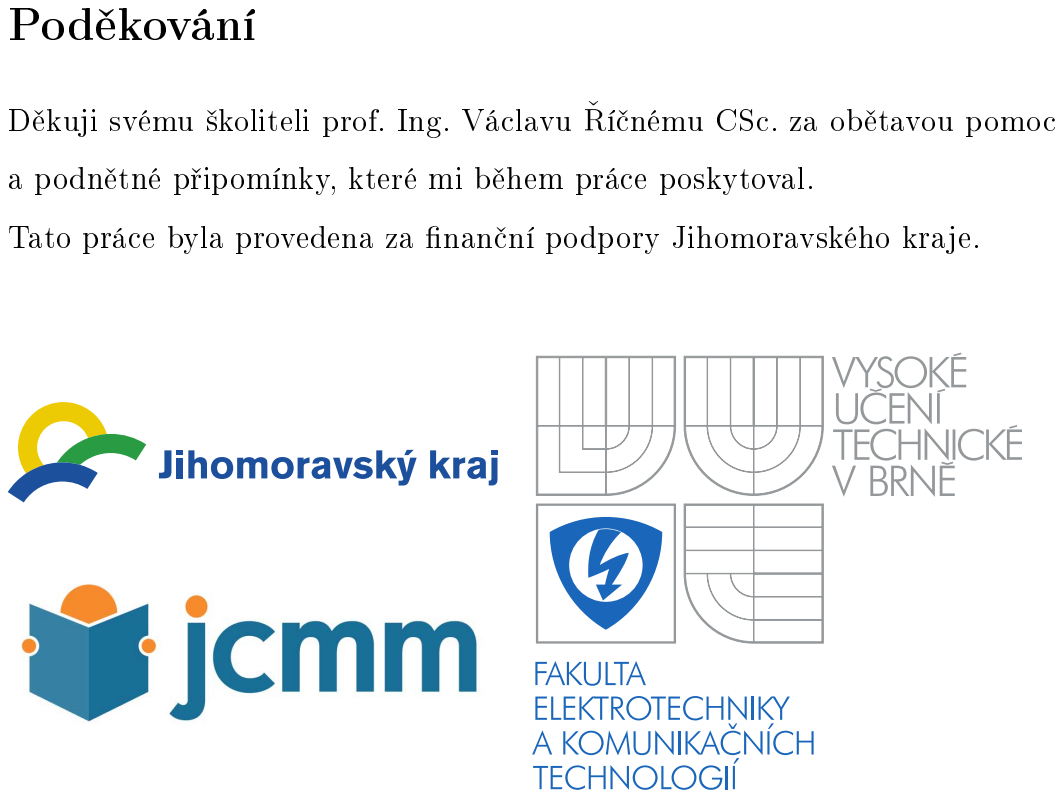
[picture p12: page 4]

## Anotace

Cílem této práce je navrhnout a sestavit chytrou zásuvku, která se ovládá po-

mocí pomocí SMS a která m·ºe spínat odporovou zát¥º aº 10 A. Sou£ástí mé

práce je technická dokumentace výrobku, popis postupu výroby a samotný

výrobek.

### Klí£ová slova

GSM; SMS; IQRF; relé

## Annotation

The goal of this work is to design and build a smart power socket, which

is controlled by a text message and it can switch resistive loads up to a

current 10 A. My work includes a technical documentation, description of

the manufacturing process and the product itself.

### Keywords

GSM; text message; IQRF; relay

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

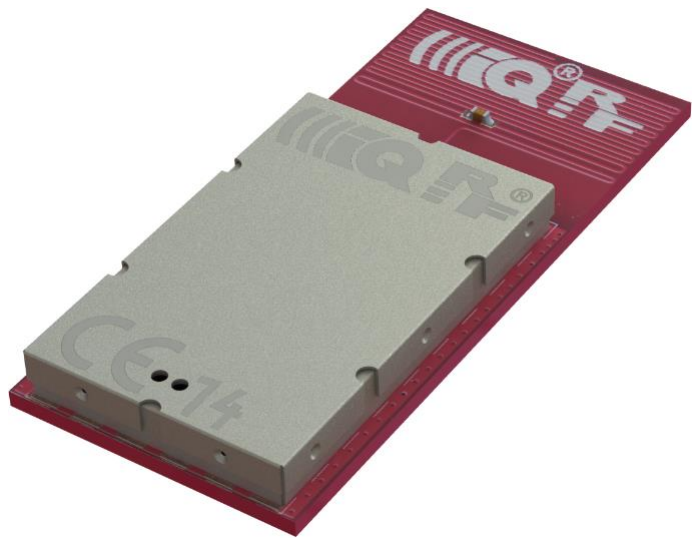
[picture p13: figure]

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

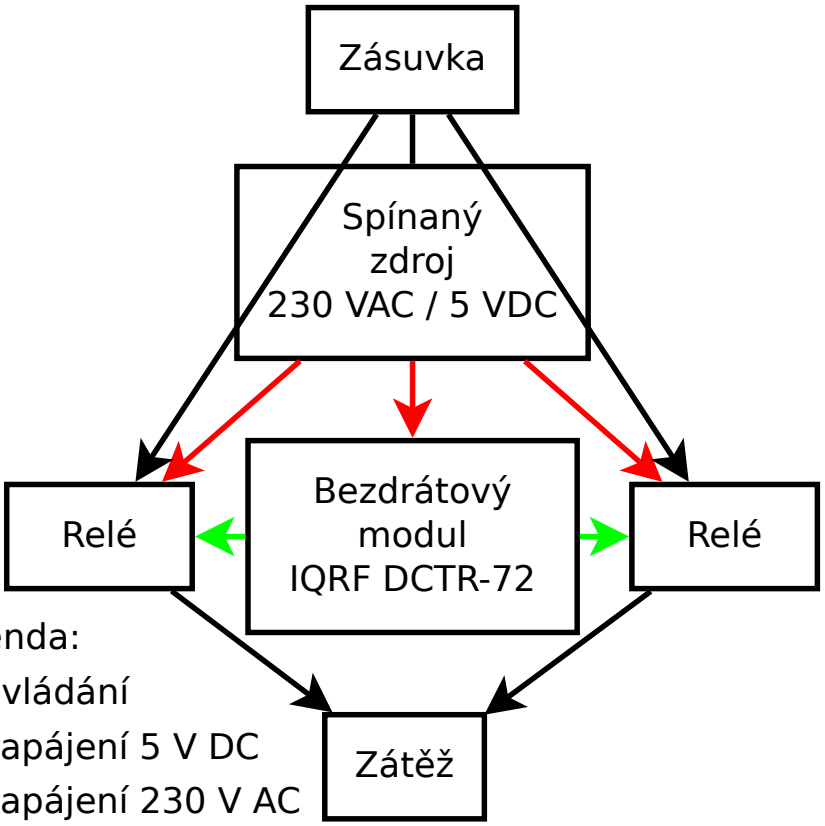
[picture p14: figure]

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

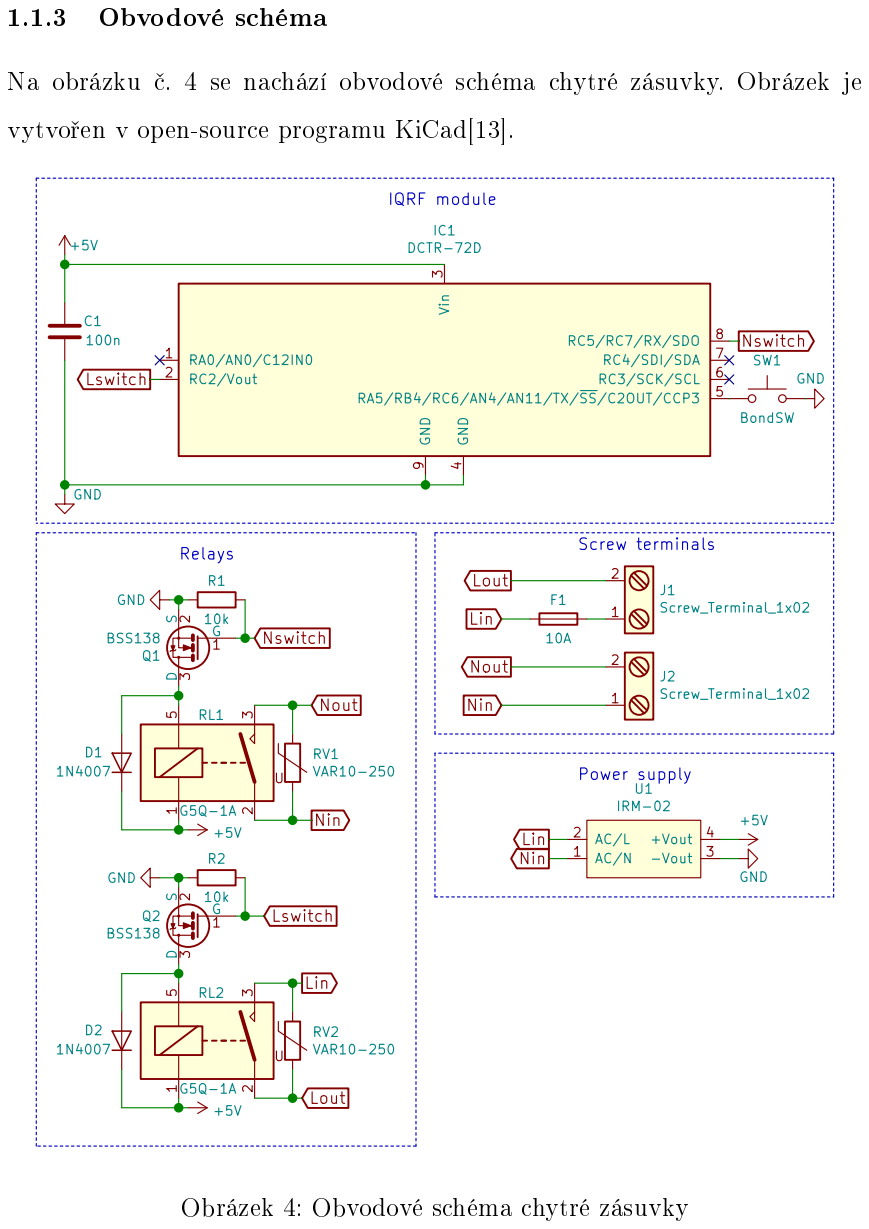
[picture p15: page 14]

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

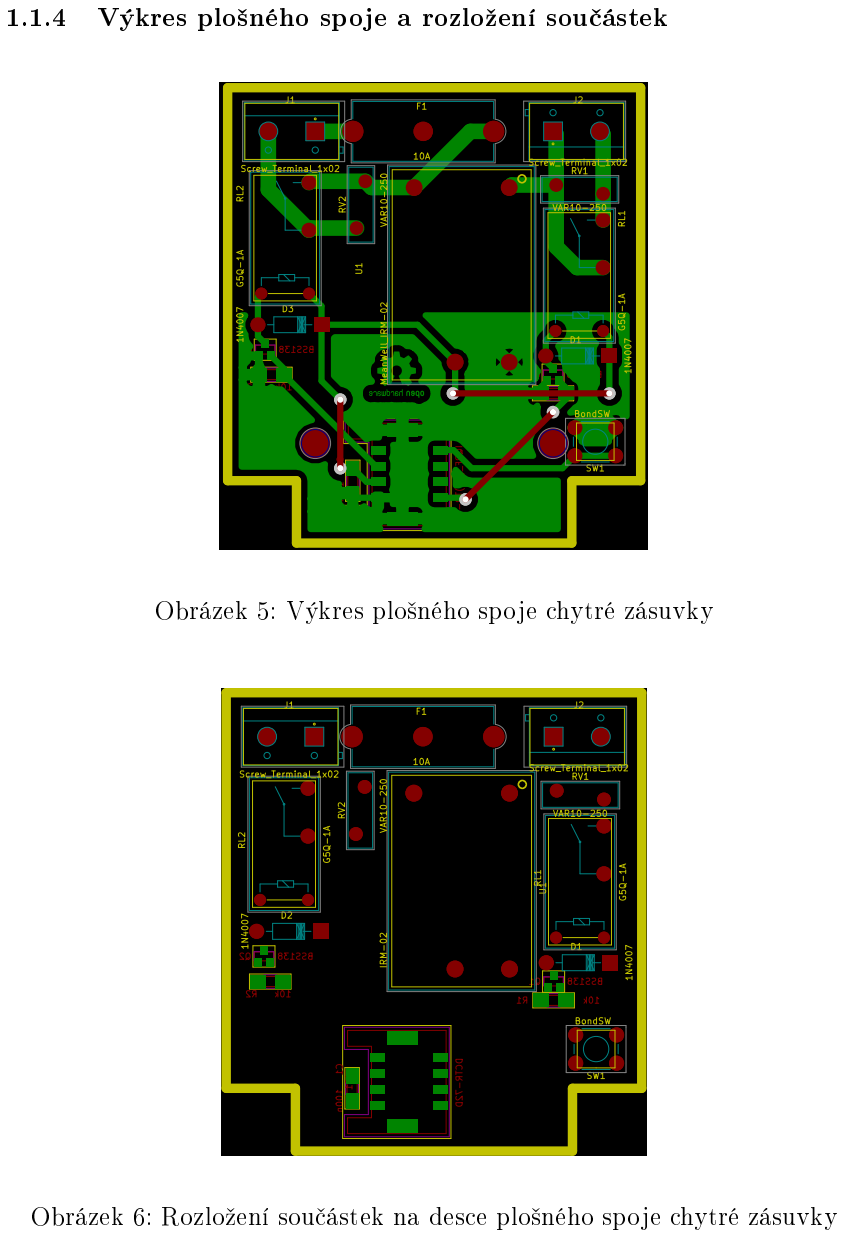
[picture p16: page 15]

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

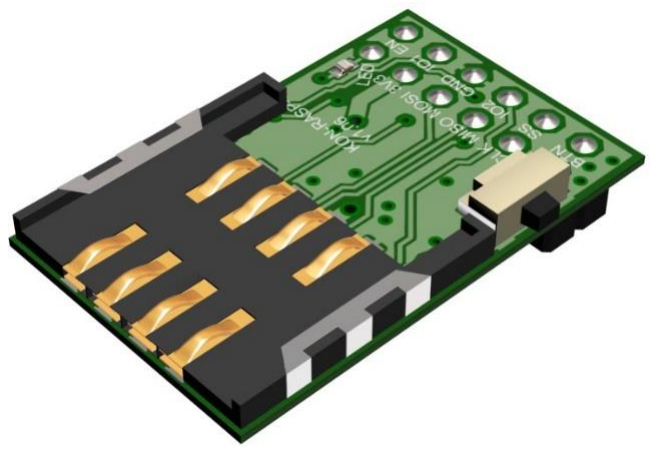
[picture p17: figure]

1.2.1 Raspberry Pi 2 model B

Raspberry Pi 2 model B je jednodeskový po£íta£, který má rozm¥ry podobné

kreditní kart¥. Tento po£íta£ obsahuje:

- £ty°jádrový ARM Cortex-A7 Broadcom BCM2836, který pracuje na
| frekvenci 900 MHz,
- 1 GB opera£ní pam¥ti RAM,
- £ty°i USB 2.0 porty
- Ethernet port pro 100 Mb sí´ovou kartu,
- microSD slot,
- HDMI výstup,
- 40 GPIO pin·,
- sb¥rnice SPI, I2C, USART.

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

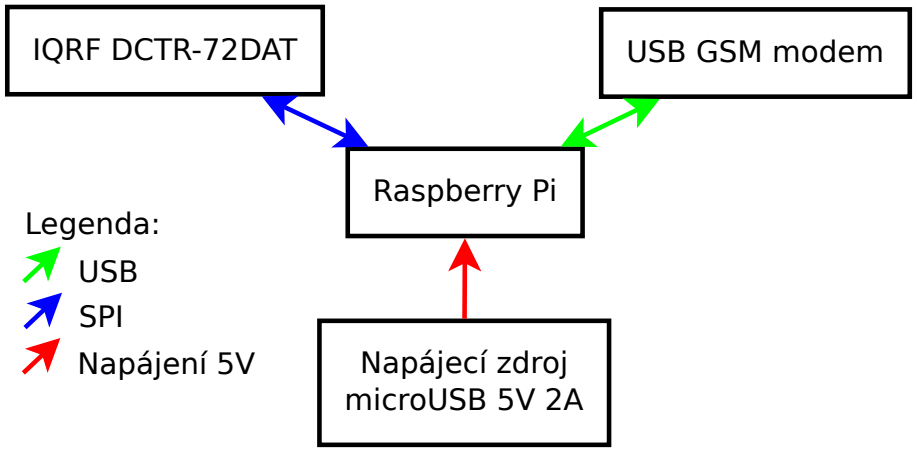
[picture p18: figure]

2 | Návrh software
2.1 | Chytrá zásuvka

Software chytré zásuvky je psán v programovacím jazyce C. Pro práci s pe-

riferiemi bezdrátového modulu je pouºita sada funkcí IQRF OS.

2.1.1 IQRF OS

IQRF OS je sada funkcí psaná v programovacím jazyce C, které m·ºe uºiva-

tel ze svého programu volat pomocí hlavi£kových soubor· IQRF-functions.h,

IQRF-macros.h, IQRF-memory.h a template-basic.h. Tyto funkce °ídí komu-

nikaci s integrovaným obvodem, který se stará o rádiovou komunikaci, o ko-

munikaci v mesh síti, o komunikaci p°es sb¥rnici SPI, o práci s pam¥tmi RAM,

EEPROM, o £tení hodnot z integrovaného teplotního senzoru, o £tení hodnot

z analogov¥ digitálního p°evodníku, o generování PWM výstupu, o iniciali-

zaci vstupních a výstupních vývod· mikrokontroléru, o £tení hodnot z vstup-

ních vývod· mikrokontroléru, o spínání výstupních pin· mikrokontroléru a

o správu LED diod, které jsou integrovány v bezdrátovém modulu.

2.1.2 IQRF DPA

IQRF DPA je vrstva nad IQRF OS, která se stará o protokol komunikace

IQRF bezdrátových modul·. IQRF DPA má pevn¥ danou strukturu paket·,

která je uvedena v tabulce £. 2. Centrální prvek v IQRF mesh síti se jme-

nuje koordinátor, který je umíst¥n v brán¥. Koordinátor má se své pam¥ti

EEPROM uloºené informace o dal²ích bezdrátových modulech, se kterými

má komunikovat. Pokud koordinátor p°ijme data od bezdrátového modulu,

jehoº informace nemá uloºené v EEPROM pam¥ti, pak data ignoruje.

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

## Reference

[1] Wikipedia. ISM Band Wikipedia [online]. [cit. 2016-01-08].

Dostupné z: https://en.wikipedia.org/wiki/ISM\_band

[2] Wikipedia. Hayes command set Wikipedia [online]. [cit. 2016-01-08].

Dostupné z: https://en.wikipedia.org/wiki/Hayes\_command\_set

[3] MICRORISC. IQRF IDE IQRF [online]. Ji£ín, 2016 [cit. 2017-01-09].

Dostupné z: http://iqrf.org/technology/iqrf-ide

[4] MICRORISC. Operating system IQRF [online]. Ji£ín, 2016 [cit. 2017-

01-09].

Dostupné z: http://iqrf.org/technology/operating-system

[5] MICRORISC. DPA IQRF [online]. Ji£ín, 2016 [cit. 2017-01-09].

Dostupné z: http://iqrf.org/technology/dpa

[6] MICRORISC. Datasheet DCTR-72D IQRF [online]. Ji£ín, 2016 [cit.

2017-01-09].

Dostupné z: http://iqrf.org/weben/downloads.php?id=337

[7] MICRORISC. Datasheet KON-RASP-01 IQRF [online]. Ji£ín, 2016 [cit.

2017-01-23].

Dostupné z: http://www.iqrf.org/weben/downloads.php?id=412

[8] Jiri Bezstarosti. Tranzistor jako spína£ Robodoup¥ [online]. 2012 [cit.

2017-01-09].

Dostupné z: http://robodoupe.cz/2012/tranzistor-jako-spinac/

[9] Jaroslav Borovec. Fáze vlevo nebo vpravo, v £em tkví nebezpe£í?

Eletrika.cz [online]. 2009 [cit. 2017-01-09].

Dostupné | z: | http://elektrika.cz/clanky/

faze-vlevo-nebo-vpravo-v-cem-tkvi-nebezpeci

[10] Old°ich Mrázek. P°ehled zásuvek pouºívaných ve sv¥t¥ - Typ E HW

Server [online]. 2009 [cit. 2017-01-09].

Dostupné z: http://zasuvky.hw.cz/index2.php#E

[11] Brian Dipert. Teardown: WeMo Switch is highly integrated EDN

[online]. 2015 [cit. 2017-01-09].

Dostupné | z: | http://www.edn.com/design/consumer/4440797/

Teardown--WeMo-Switch-is-highly-integrated

[12] Dia Dia [online]. [cit. 2017-01-19].

Dostupné z: https://wiki.gnome.org/Apps/Dia/

[13] KiCad EDA KiCad EDA [online]. [cit. 2017-01-19].

Dostupné z: http://kicad-pcb.org/

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

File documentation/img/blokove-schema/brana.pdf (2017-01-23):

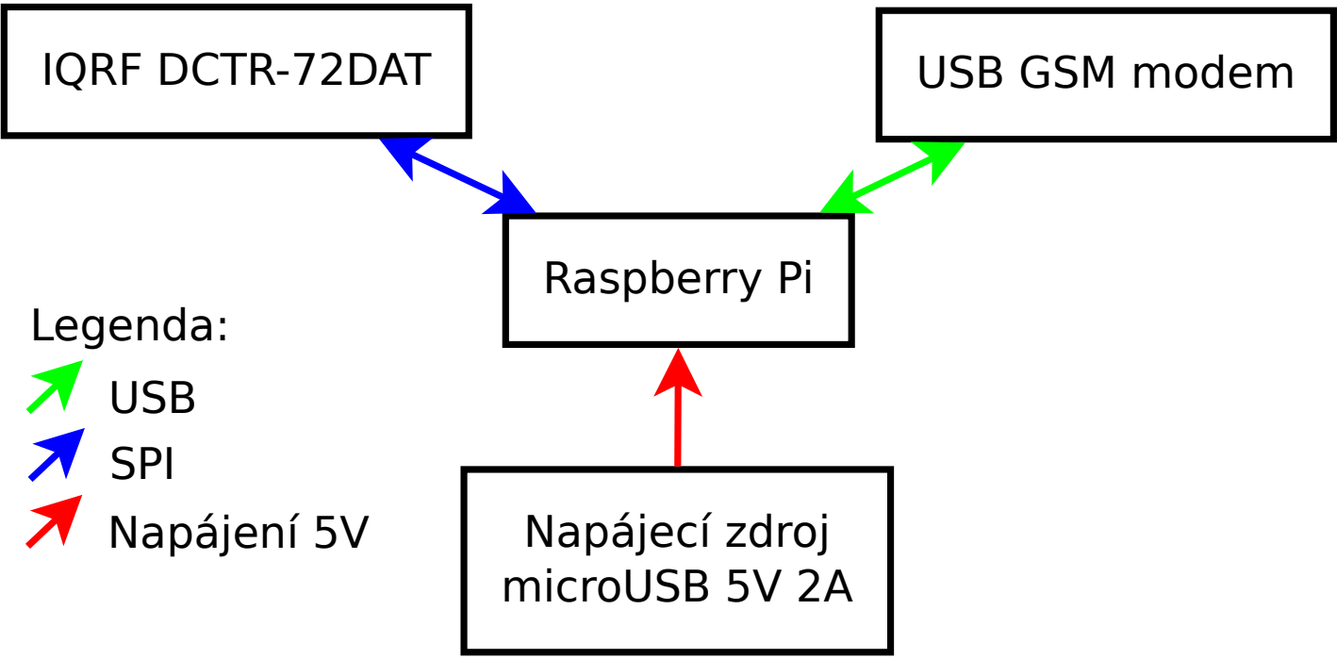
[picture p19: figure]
Raspberry Pi; Napájecí zdroj microUSB 5V 2A; IQRF DCTR-72DAT; USB GSM modem; USB SPI Napájení 5V; Legenda:

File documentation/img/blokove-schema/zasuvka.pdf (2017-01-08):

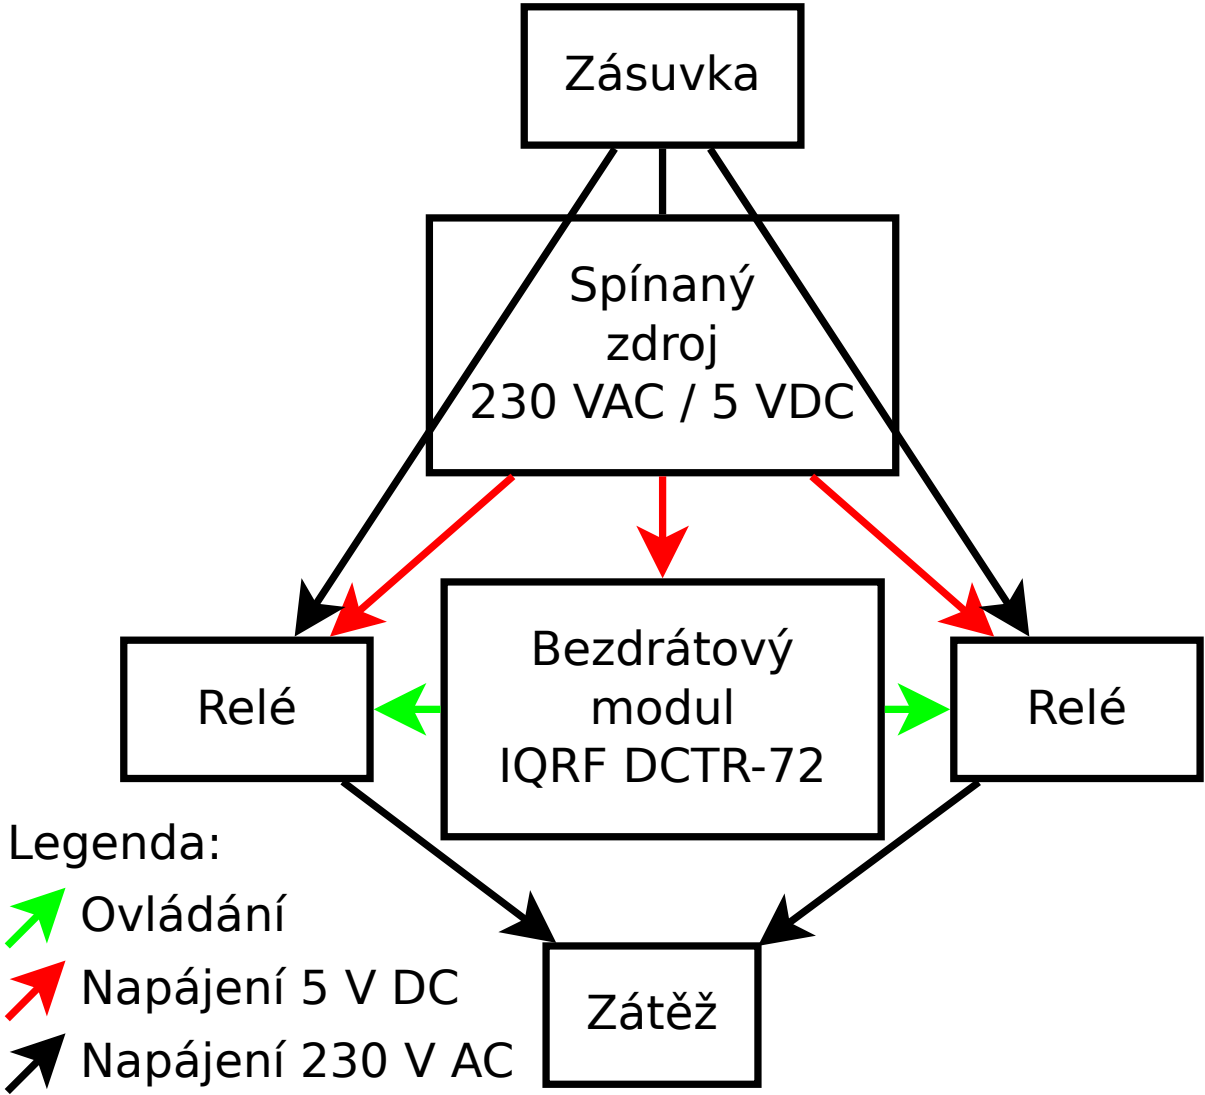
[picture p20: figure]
Bezdrátový modul IQRF DCTR-72; Relé; Spínaný zdroj 230 VAC / 5 VDC; Napájení 5 V DC; Ovládání; Zátěž; Zásuvka; Napájení 230 V AC; Legenda:

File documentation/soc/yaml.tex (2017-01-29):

\newcommand\YAMLcolonstyle{\color{red}\mdseries}
\newcommand\YAMLkeystyle{\color{black}\bfseries}
\newcommand\YAMLvaluestyle{\color{blue}\mdseries}

\makeatletter

% here is a macro expanding to the name of the language
% (handy if you decide to change it further down the road)
\newcommand\language@yaml{yaml}

\expandafter\expandafter\expandafter\lstdefinelanguage
\expandafter{\language@yaml}
{
  keywords={true,false,null,y,n},
  keywordstyle=\color{darkgray}\bfseries,
  basicstyle=\YAMLkeystyle,                                 % assuming a key comes first
  sensitive=false,
  comment=[l]{\#},
  morecomment=[s]{/*}{*/},
  commentstyle=\color{purple}\ttfamily,
  stringstyle=\YAMLvaluestyle\ttfamily,
  moredelim=[l][\color{orange}]{\&},
  moredelim=[l][\color{magenta}]{*},
  moredelim=**[il][\YAMLcolonstyle{:}\YAMLvaluestyle]{:},   % switch to value style at :
  morestring=[b]',
  morestring=[b]",
  literate =    {---}{{\ProcessThreeDashes}}3
                {>}{{\textcolor{red}\textgreater}}1     
                {|}{{\textcolor{red}\textbar}}1 
                {\ -\ }{{\mdseries\ -\ }}3,
}

% switch to key style at EOL
\lst@AddToHook{EveryLine}{\ifx\lst@language\language@yaml\YAMLkeystyle\fi}
\makeatother

\newcommand\ProcessThreeDashes{\llap{\color{cyan}\mdseries-{-}-}}

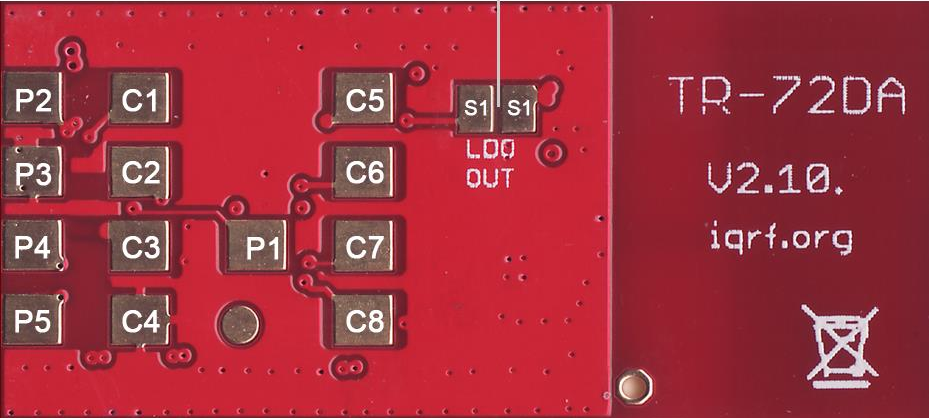
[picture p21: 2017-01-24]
documentation/img/iqrf/iqrf-pinout.png

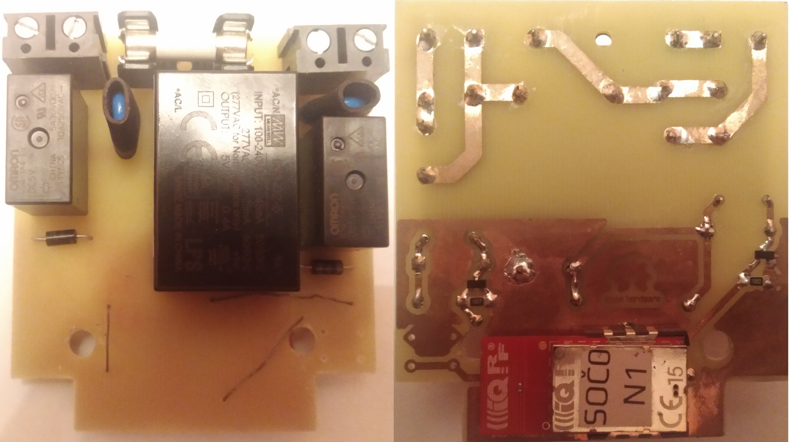
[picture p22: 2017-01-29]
documentation/img/foto/zasuvka-deska.jpg

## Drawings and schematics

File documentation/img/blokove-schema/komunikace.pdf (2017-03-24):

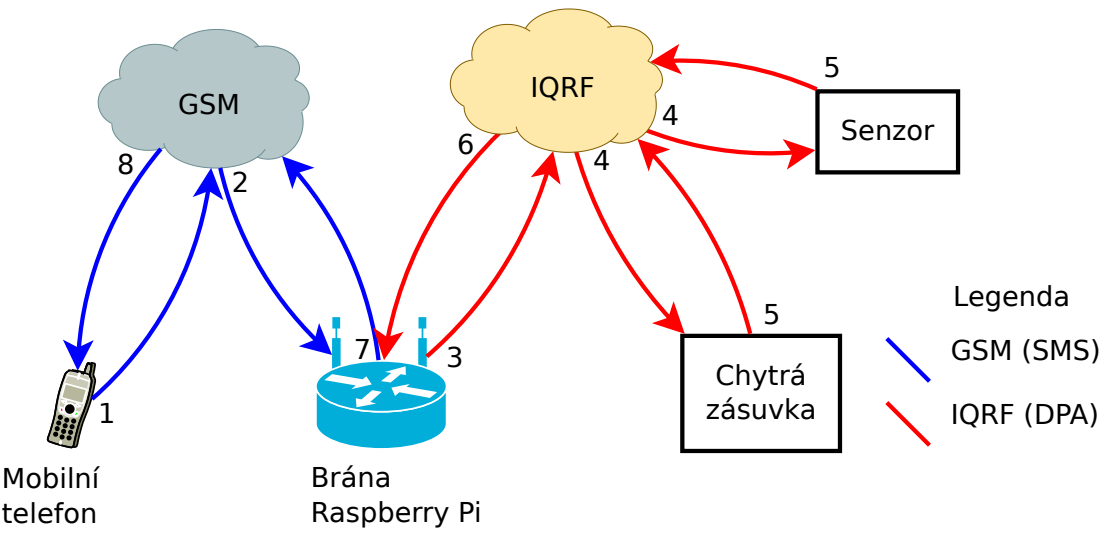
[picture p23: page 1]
GSM; Chytrá zásuvka; Senzor; Mobilní telefon; Brána Raspberry Pi; Legenda; GSM (SMS); IQRF (DPA); IQRF

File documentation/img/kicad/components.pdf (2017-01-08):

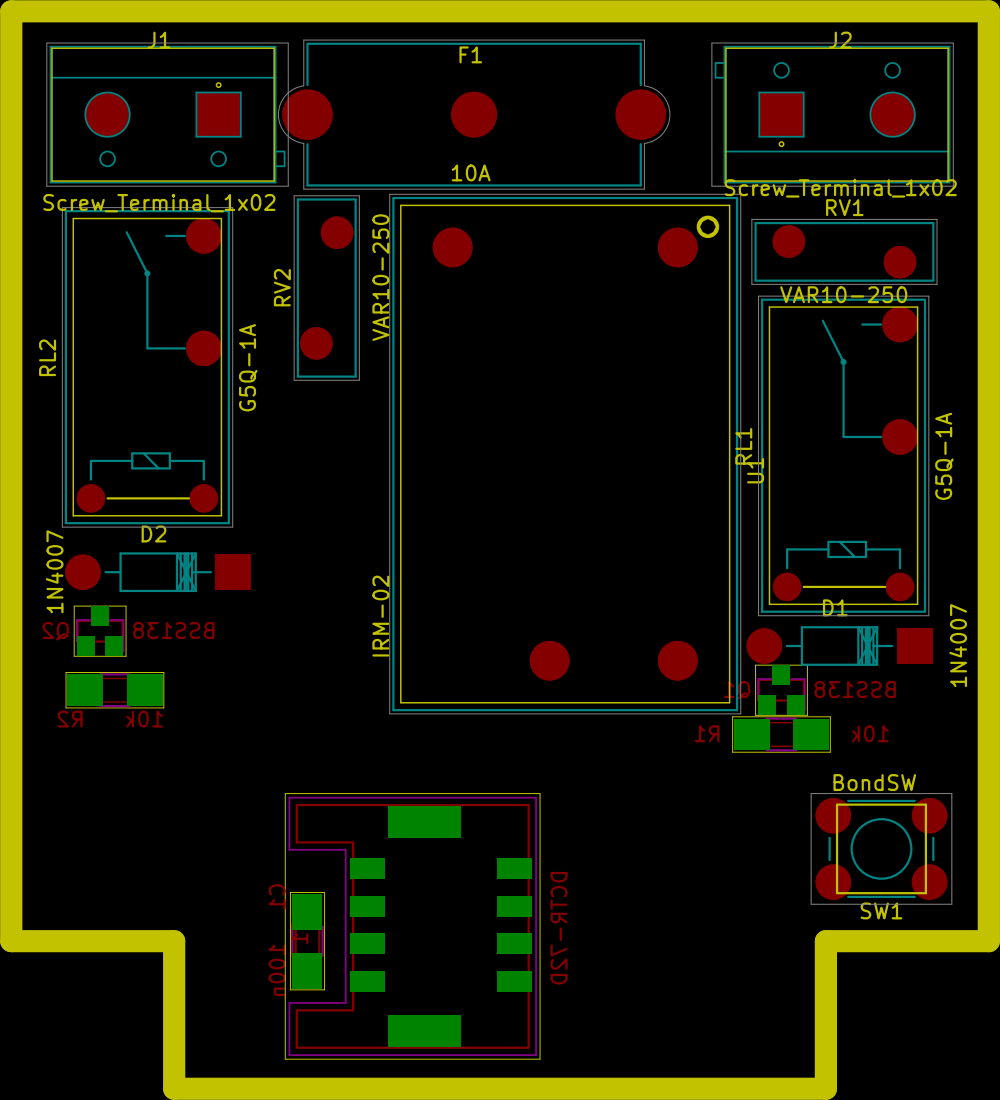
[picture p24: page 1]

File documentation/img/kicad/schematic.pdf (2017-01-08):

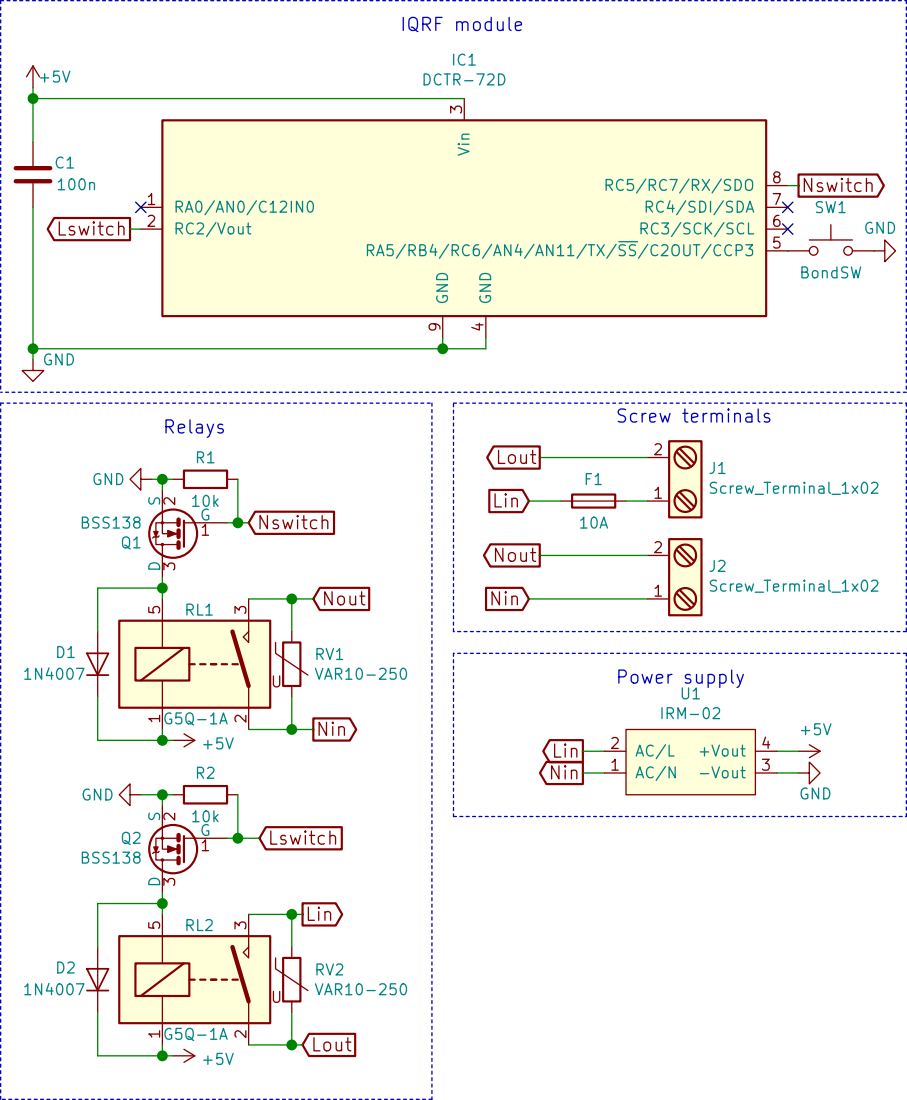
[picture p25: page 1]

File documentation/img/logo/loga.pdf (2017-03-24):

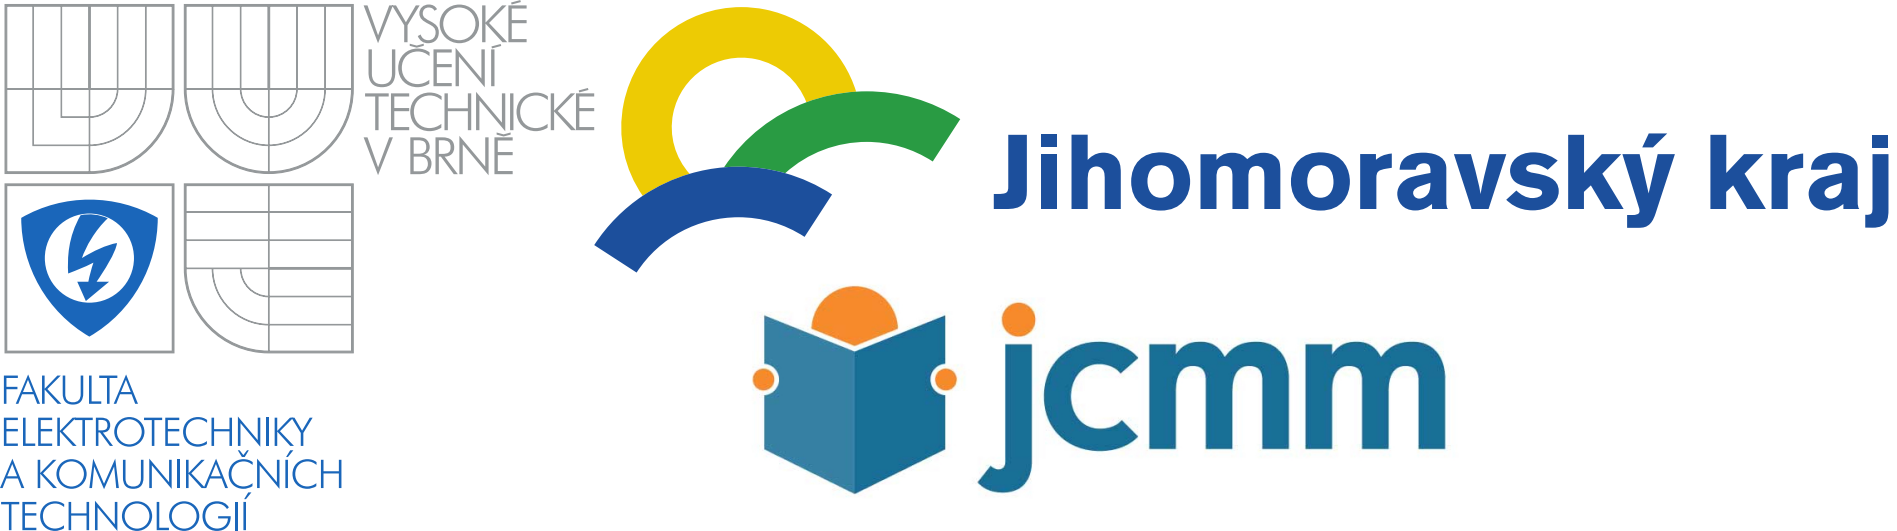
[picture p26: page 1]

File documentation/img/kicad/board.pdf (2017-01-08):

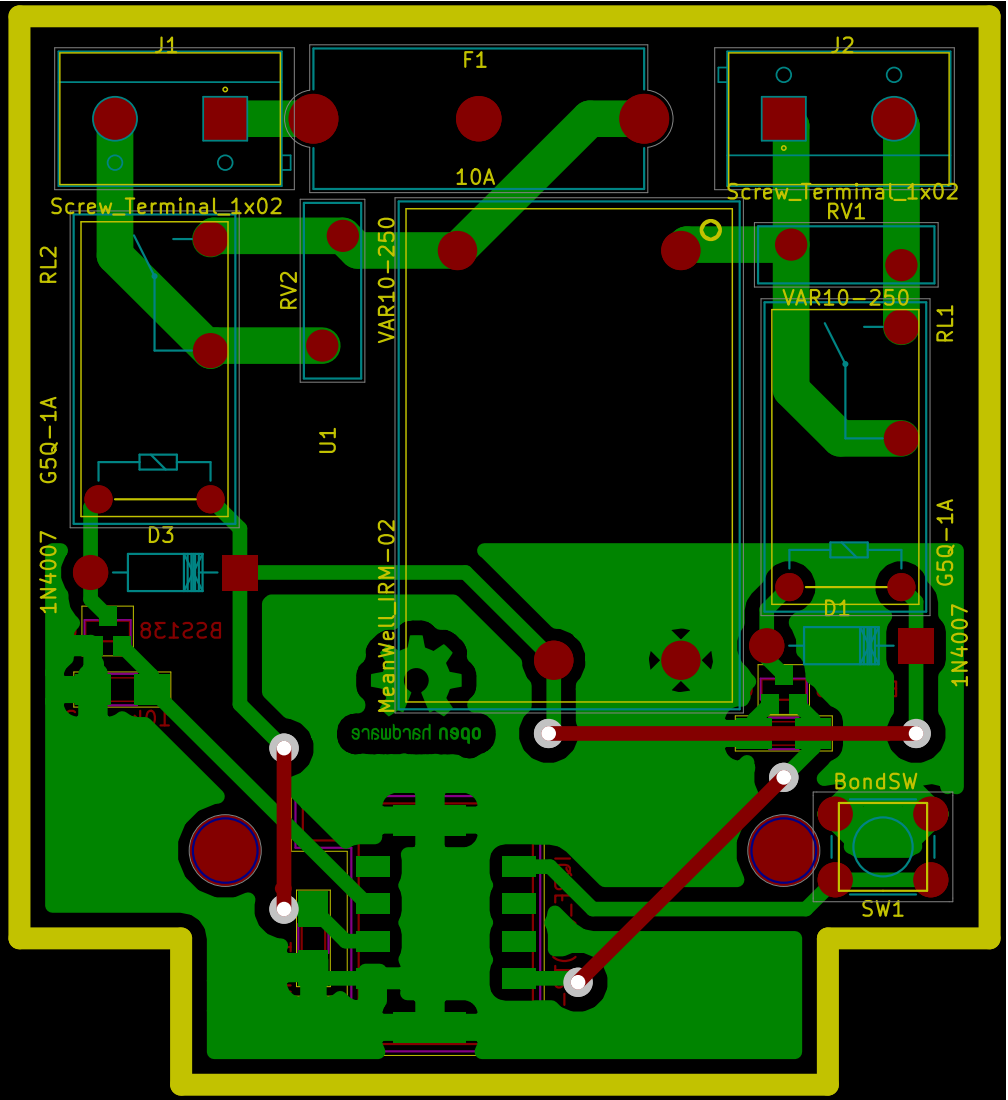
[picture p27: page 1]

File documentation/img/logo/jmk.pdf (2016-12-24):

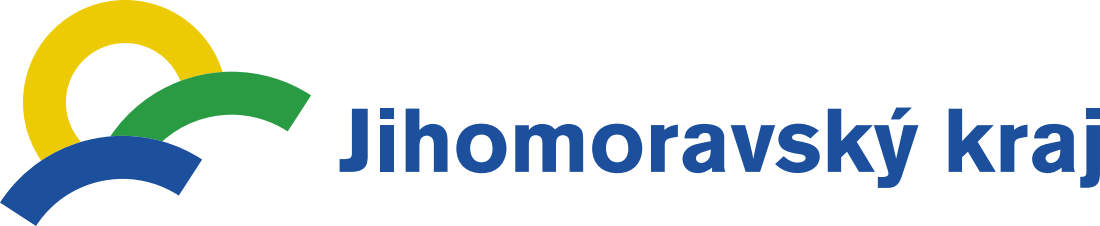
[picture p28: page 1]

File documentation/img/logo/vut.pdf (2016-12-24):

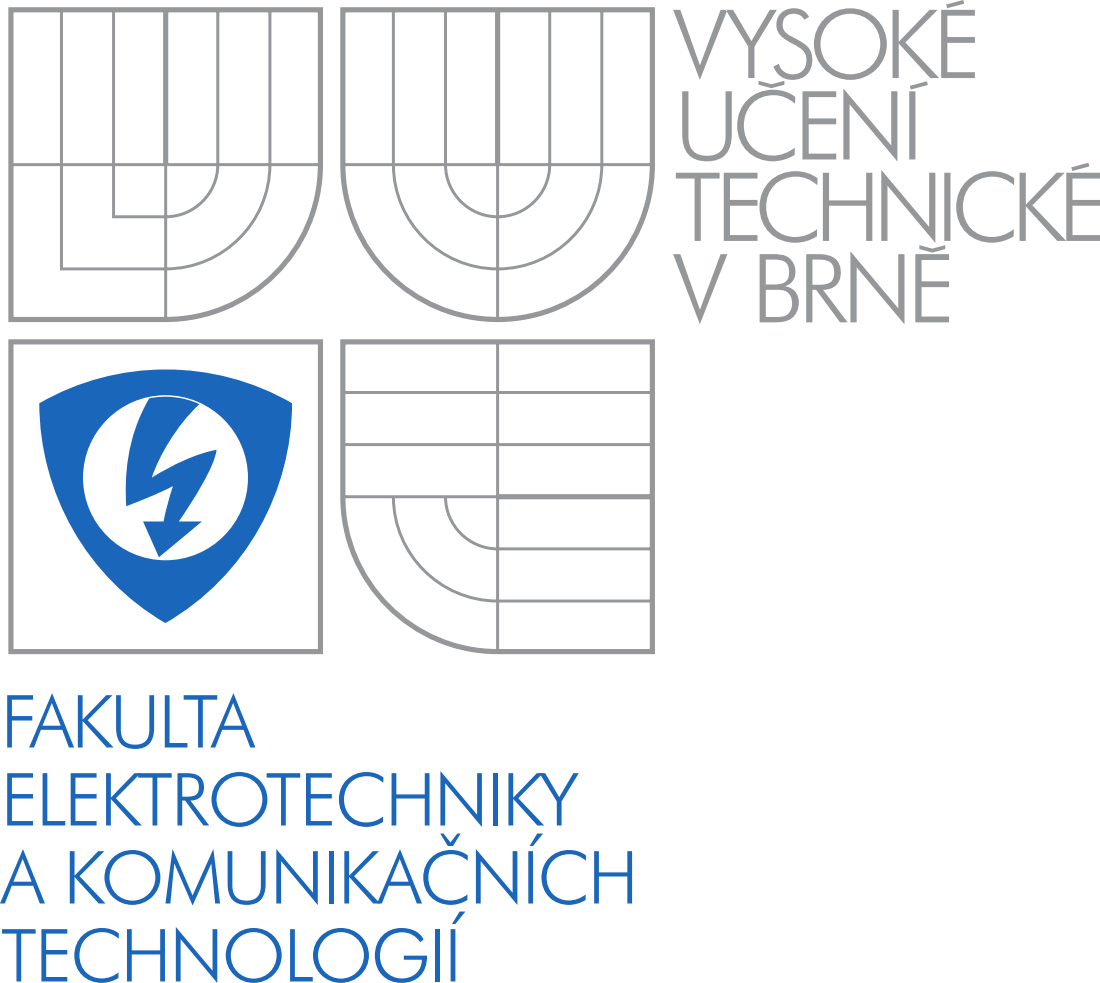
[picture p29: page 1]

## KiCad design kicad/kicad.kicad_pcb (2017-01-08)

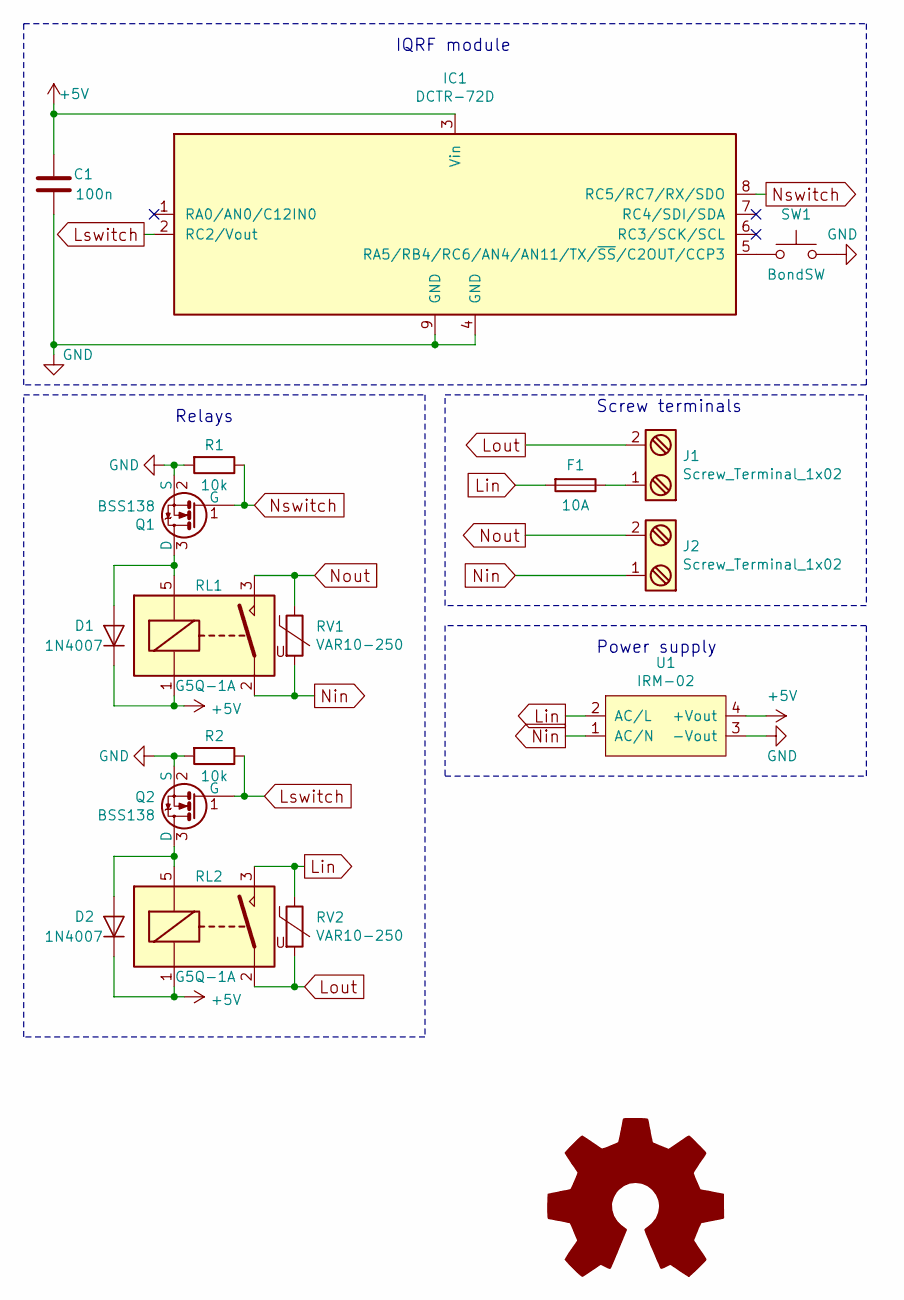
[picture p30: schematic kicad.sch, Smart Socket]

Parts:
C1: 100n; C_1206_HandSoldering
D1, D2: 1N4007; Diode_DO-41_SOD81_Horizontal_RM10
F1: 10A; Fuseholder5x20_horiz_open_Schurter_0031_8201
IC1: DCTR-72D; IQRF_KON-SIM-01
J1, J2: Screw_Terminal_1x02; TerminalBlock_DG300-7.5-02P_RM7.5mm_2pol
LOGO1: OPEN_HARDWARE_2; OSHW-Logo2_9.8x8mm_Copper
Q1, Q2: BSS138; SOT-23
R1, R2: 10k; R_1206_HandSoldering
RL1, RL2: G5Q-1A; Relay_SPST-NO_OMRON-G5Q
RV1, RV2: VAR10-250; RV_Disc_D12_W3.9_P7.5
SW1: BondSW; SW_PUSH_6mm
U1: IRM-02; ACDC-Converter_MeanWell-IRM-02-x

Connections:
+5V: C1.2, D1.1 (K), D2.1 (K), IC1.3 (Vin), RL1.1, RL2.1, U1.4 (+Vout)
GND: C1.1, IC1.4 (GND), IC1.9 (GND), Q1.2 (S), Q2.2 (S), R1.2, R2.2, SW1.2, U1.3 (-Vout)
Lin: F1.2, RL2.3, RV2.1, U1.2 (AC/L)
Lout: J1.2, RL2.2, RV2.2
Lswitch: IC1.2 (RC2/Vout), Q2.1 (G), R2.1
unnamed: D1.2 (A), Q1.3 (D), RL1.5
unnamed: D2.2 (A), Q2.3 (D), RL2.5
unnamed: F1.1, J1.1
unnamed: IC1.5 (RA5/RB4/RC6/AN4/AN11/TX/~SS~/C2OUT/CCP3), SW1.1
Nin: J2.1, RL1.2, RV1.2, U1.1 (AC/N)
Nout: J2.2, RL1.3, RV1.1
Nswitch: IC1.8 (RC5/RC7/RX/SDO), Q1.1 (G), R1.1

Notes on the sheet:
Relays
IQRF module
Screw terminals
Power supply

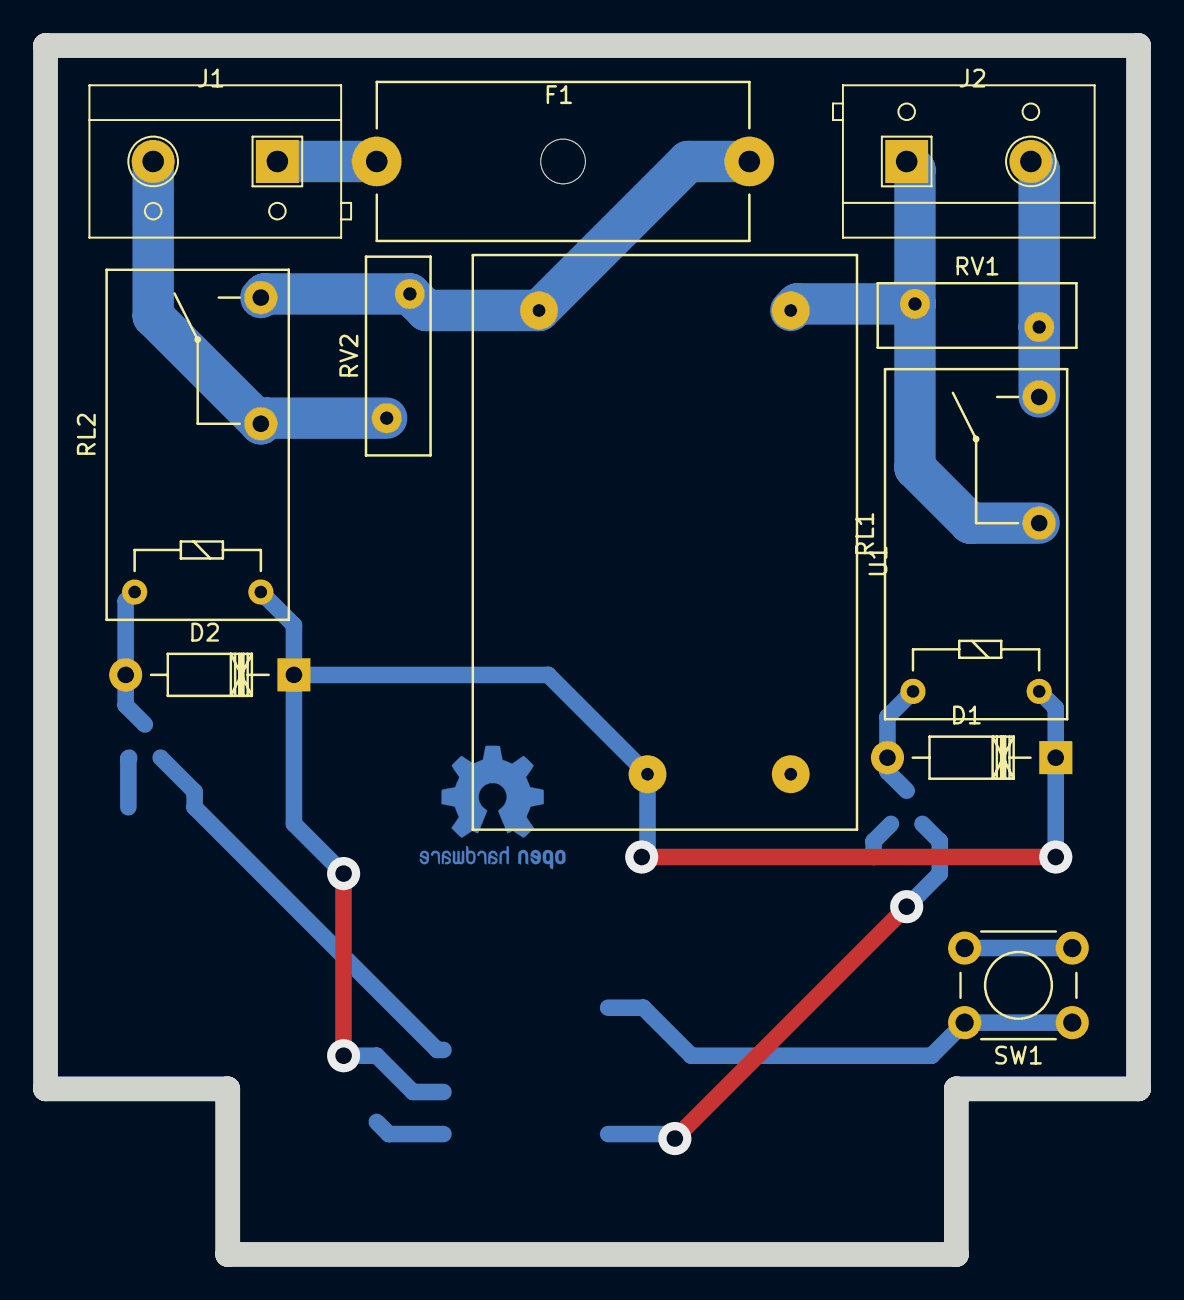
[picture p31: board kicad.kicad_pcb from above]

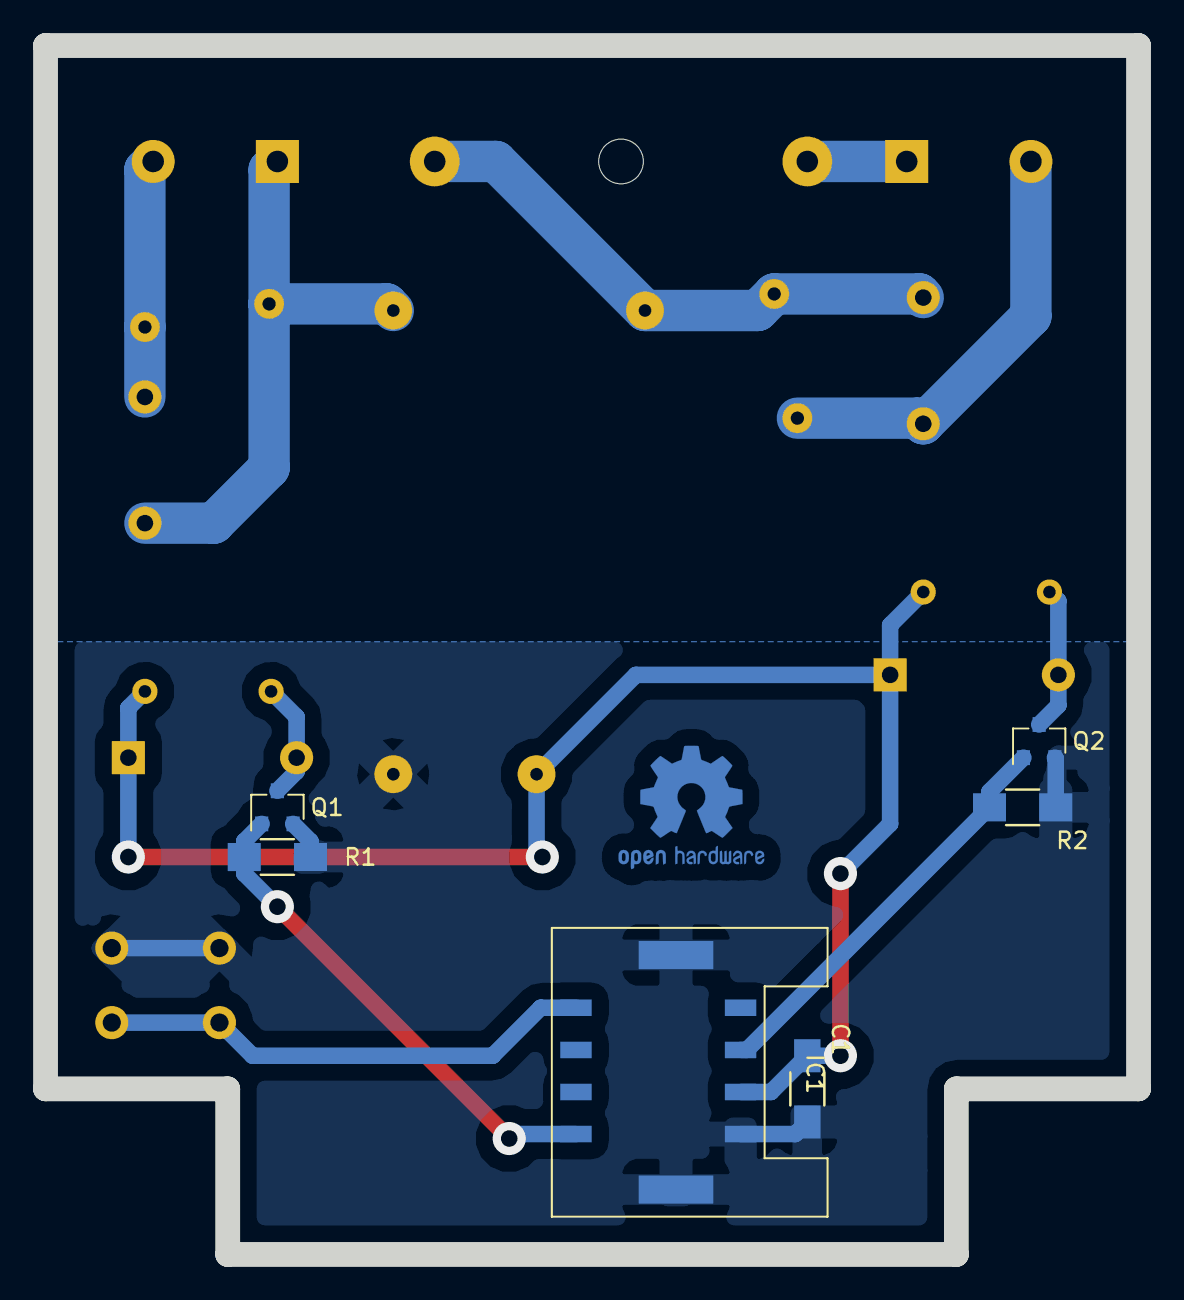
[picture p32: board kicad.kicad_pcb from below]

Board: 2 copper layers, 66.0 x 73.0 mm, 18 parts (7 on the bottom side), 12 nets.

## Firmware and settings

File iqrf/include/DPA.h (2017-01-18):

// *********************************************************************
//   General public DPA header file                                    *
// *********************************************************************
//
// File:    $RCSfile: DPA.h,v $
// Version: $Revision: 1.185 $
// Date:    $Date: 2016/09/29 13:15:36 $
//
// Revision history:
//   2016/09/12  Release for DPA 2.28
//   2016/04/14  Release for DPA 2.27
//   2016/03/03  Release for DPA 2.26
//   2016/01/21  Release for DPA 2.25
//   2015/12/01  Release for DPA 2.24
//   2015/10/23  Release for DPA 2.23
//   2015/09/25  Release for DPA 2.22
//   2015/09/03  Release for DPA 2.21
//   2015/08/05  Release for DPA 2.20
//   2014/10/31  Release for DPA 2.10
//   2014/04/30  Release for DPA 2.00
//   2013/10/03  Release for DPA 1.00
//
// *********************************************************************

// Online DPA documentation http://www.iqrf.org/DpaTechGuide/

#ifndef _DPA_HEADER_
#define _DPA_HEADER_

//############################################################################################

// DPA version
#define	DPA_VERSION_MASTER		0x0228

#ifdef __CC5X__
// Compiled only at CC5X
#if __CC5X__ < 3503
#error Insufficient CC5X compiler version, V3.5C is minimum
#endif

// Bank for custom variables
#pragma rambank = 11

// Main DPA API entry address (also start of the licensed FLASH) 
#define	DPA_API_ADDRESS			__LICENSED_FLASH

// Main DPA entry address
#define	MAIN_DPA_ADDRESS		( DPA_API_ADDRESS + 4 )

// Main DPA API entry address stub
#define	DPA_API_ADDRESS_ENTRY		0x3A08

// Address of the DPA Custom Handler
#define	CUSTOM_HANDLER_ADDRESS		0x3A20

// Address of the DPA Custom Handler end + 1
#if defined( TR7xD )
#define	CUSTOM_HANDLER_ADDRESS_END	0x3D80
#elif defined ( TR5xD )
#define	CUSTOM_HANDLER_ADDRESS_END	0x3D00
#else
#error Unsupported DCTR type
#endif

// DPA API entry function
uns8  DpaApiEntry( uns8 par1, uns8 par2, uns8 apiIndex );

// DPA API codes
#define	DPA_API_RFTX_DPAPACKET				0
#define	DPA_API_READ_CONFIG_BYTE			1
#define	DPA_API_SEND_TO_IFACEMASTER			2
#define	DPA_API_COORDINATOR_RFTX_DPAPACKET	3
#define	DPA_API_LOCAL_REQUEST				4
#define	DPA_API_SET_PERIPHERAL_ERROR		5

// Used buffer size symbols
#define	sizeofBufferAUX sizeof( bufferAUX )
#define	sizeofBufferCOM sizeof( bufferCOM )

#define	STRUCTATTR

#else
// Not compiled at CC5X

// Define CC5X types
typedef uint8_t	  uns8;
typedef uint16_t  uns16;

// Fake buffer sizes
#define	sizeofBufferAUX 64
#define	sizeofBufferCOM 64

// Disables alignment of members of structures
#define	STRUCTATTR	__attribute__((packed))

#endif

// Indices of configuration bytes used by DpaApiReadConfigByte( index )
// Checksum
#define	CFGIND_CHECKSUM			0x00
// Standard peripherals
#define	CFGIND_DPA_PERIPHERALS	0x01
// DPA configuration flags
#define	CFGIND_DPA_FLAGS		0x05
// Main RF channel, used by the subordinate network
#define	CFGIND_CHANNEL_2ND_A	0x06
// Second RF channel, used by the subordinate network
#define	CFGIND_CHANNEL_2ND_B	0x07
// TX power
#define	CFGIND_TXPOWER 			0x08
// RX filter used by checkRF()
#define	CFGIND_RXFILTER			0x09
// toutRF for LP mode
#define	CFGIND_DPA_LP_TOUTRF	0x0A
// UART interface baud rate
#define	CFGIND_DPA_UART_IFACE_SPEED 0x0B
// Alternate DSM channel
#define	CFGIND_ALTERNATE_DSM_CHANNEL 0x0C
// Main RF channel
#define	CFGIND_CHANNEL_A		0x11
// Second RF channel
#define	CFGIND_CHANNEL_B		0x12

// 0: checks only mandatory precondition in order to prevent critical side-effects
// 1: as above plus checks meaningful parameter conditions
// 2: full implemented parameter checking (default)
#ifndef PARAM_CHECK_LEVEL
#define	PARAM_CHECK_LEVEL 2
#endif

// "foursome" at IFace structure
typedef struct
{
  // Node address low byte
  uns8	NADRlow;
  // Node address high byte
  uns8	NADRhigh;
  // Peripheral number
  uns8	PNUM;
  // Peripheral command
  uns8	PCMD;
  // HWPID
  uns16	HWPID;
} STRUCTATTR TDpaIFaceHeader;

// Maximum command PCMD value
#define	MAX_PCMD					0x3f
// Bit mask at PCMD that indicates DPA Response message
#define	RESPONSE_FLAG				0x80

// IQMESH coordinator address
#define COORDINATOR_ADDRESS			0x00
// IQMESH broadcast address
#define BROADCAST_ADDRESS			0xff
// IQMESH temporary address, assigned by remote bonding before authorization is done
#define TEMPORARY_ADDRESS			0xfe
// Address of the local device addressed by IFace
#define LOCAL_ADDRESS				0xfc
// Maximum IQMESH network device address
#define MAX_ADDRESS					( 240 - 1 )
// Maximum number of DPA peripherals per device
#define MAX_PERIPHERALS				0x70

// Time slots lengths in 10 ms
#define	MIN_STD_TIMESLOT	3	
#ifdef TR7xD
#define	MAX_STD_TIMESLOT	5
#else
#define	MAX_STD_TIMESLOT	6
#endif

#define	MIN_LP_TIMESLOT		8
#define	MAX_LP_TIMESLOT		10

#ifdef DPA_STD
#define	MIN_TIMESLOT		MIN_STD_TIMESLOT	
#define	MAX_TIMESLOT		MAX_STD_TIMESLOT
#else
#define	MIN_TIMESLOT		MIN_LP_TIMESLOT	
#define	MAX_TIMESLOT		MAX_LP_TIMESLOT	
#endif

// Long diagnostics slot time
#define	LONG_DIAG_TIMESLOT	20 

// Maximum number of DPA PData bytes ( minus 8 = 6B foursome + 8b error code + 8b DpaValue )
#define DPA_MAX_DATA_LENGTH			( sizeofBufferCOM - sizeof( TDpaIFaceHeader ) - 2 * sizeof( uns8 ) )

// Maximum number of peripherals info that can fit in the message
#define MAX_PERIPHERALS_PER_BLOCK_INFO	( DPA_MAX_DATA_LENGTH / sizeof( TPeripheralInfoAnswer ) )

// Standard peripheral numbers
#define  PNUM_COORDINATOR	0x00
#define  PNUM_NODE			0x01
#define  PNUM_OS			0x02
#define  PNUM_EEPROM		0x03
#define  PNUM_EEEPROM		0x04
#define  PNUM_RAM			0x05
#define  PNUM_LEDR			0x06
#define  PNUM_LEDG			0x07
#define  PNUM_SPI			0x08
#define  PNUM_IO			0x09
#define  PNUM_THERMOMETER	0x0A
#define  PNUM_PWM			0x0B
#define  PNUM_UART			0x0C
#define  PNUM_FRC			0x0D

// Number of the 1st user peripheral
#define  PNUM_USER			0x20
// Fake peripheral number used to flag DPA response with error sent by RF
#define  PNUM_ERROR_FLAG	0xfe
#define  PNUM_ENUMERATION	0xff

// DPA Commands for predefined peripherals
#define	CMD_COORDINATOR_ADDR_INFO  0
#define	CMD_COORDINATOR_DISCOVERED_DEVICES 1
#define	CMD_COORDINATOR_BONDED_DEVICES 2
#define	CMD_COORDINATOR_CLEAR_ALL_BONDS 3
#define	CMD_COORDINATOR_BOND_NODE 4
#define	CMD_COORDINATOR_REMOVE_BOND 5
#define	CMD_COORDINATOR_REBOND_NODE 6
#define	CMD_COORDINATOR_DISCOVERY 7
#define	CMD_COORDINATOR_SET_DPAPARAMS 8
#define	CMD_COORDINATOR_SET_HOPS 9
#define	CMD_COORDINATOR_DISCOVERY_DATA 10
#define	CMD_COORDINATOR_BACKUP 11
#define	CMD_COORDINATOR_RESTORE 12
#define	CMD_COORDINATOR_AUTHORIZE_BOND 13
#define	CMD_COORDINATOR_BRIDGE 14
#define	CMD_COORDINATOR_READ_REMOTELY_BONDED_MID 15
#define	CMD_COORDINATOR_CLEAR_REMOTELY_BONDED_MID 16
#define	CMD_COORDINATOR_ENABLE_REMOTE_BONDING 17
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

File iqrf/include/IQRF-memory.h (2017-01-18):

// *****************************************************************************
//                               IQRF - memory                                 *
// *****************************************************************************
// Intended for:
//	 HW: TR-52D, TR-54D, TR-55D, TR-56D, TR-58D, TR-72D, TR-76D
//   OS: v3.08D
//
// File:    IQRF-memory.h
// Version: v1.00                                   Revision: 12/02/2016
//
// Revision history:
//   v1.00: 12/02/2016  First release for OS 3.08D.
//
// *****************************************************************************

//******************************************************************************
// Temperature sensor configuration registers 
//******************************************************************************
#if defined TR7xD
    typedef struct                                  // Default setting: 0b0000.0100
    {
        bit resolution0;
        bit resolution1;
        bit powerDownMode;
        bit skipSetup;
    } TmpCfg;                                       // For internal usage only
#endif

// *****************************************************************************
uns8  usedBank0[80]     @ 0x020;                    // Do not use this space
uns8  usedBank1[80]     @ 0x0A0;                    // Do not use this space
uns8  usedBank2[80]     @ 0x120;                    // Do not use this space
uns8  usedBank3[80]     @ 0x1A0;                    // Do not use this space
uns8  usedBank4[80]     @ 0x220;                    // Do not use this space
uns8  usedBank5[80]     @ 0x2A0;                    // Do not use this space
uns8  usedBank6[80]     @ 0x320;                    // Do not use this space
uns8  usedBank7[80]     @ 0x3A0;                    // Do not use this space
uns8  usedBank8[80]     @ 0x420;                    // Do not use this space
uns8  usedBank9[80]     @ 0x4A0;                    // Do not use this space
uns8  usedBank10[80]    @ 0x520;                    // Do not use this space
uns8  usedBank11[32]    @ 0x5A0;                    // Do not use 32B of bank11 (0x5A0 - 0x5BF)
// user space: bank11 48B (0x5C0 - 0x5EF) , bank12: 48B (0x620 - 0x64F)

//******************************************************************************
// Dedicated buffers and file registers
//******************************************************************************
uns8    bufferINFO[64]  @ usedBank6;				// Auxiliary buffer, 64B long
uns8    bufferCOM[64]   @ usedBank7;				// Buffer for communication routines, 64B long
uns8    bufferAUX[64]   @ usedBank8;				// Auxiliary buffer, 64B long
uns8    bufferRF[64]    @ usedBank9;				// Buffer for RF routines, 64B long

uns8	X70[16]			@ 0x70;			            // Register array in shared bank for user application
uns8 	userReg0		@ X70;			            // User's register in all banks
uns8 	userReg1		@ X70[1];		            // User's register in all banks
uns8 	RFmodeByte      @ X70[2];		            // Current RF mode !!! Read Only !!!
uns8 	param2			@ X70[3];		            // Parameter_01 for function calls
uns16 	param3			@ X70[4];		            // Used as parameter for function calls
uns16 	param4			@ X70[6];		            // Used as parameter for function calls
uns8 	userInterface	@ X70[15];					// See below !!! Read Only !!!	

// Network params !!! Read Only !!!
bank11 uns8  ntwADDR            @ usedBank11[0x00]; // Network address
bank11 uns8  ntwVRN             @ usedBank11[0x01]; // VRN
bank11 uns8  ntwZIN             @ usedBank11[0x02]; // Zone index
bank11 uns8  ntwDID             @ usedBank11[0x03]; // Discovery ID
bank11 uns8  ntwPVRN          	@ usedBank11[0x04]; // Parent VRN
bank11 uns16 ntwUSERADDRESS     @ usedBank11[0x05]; // User address 2B
bank11 uns16 ntwID              @ usedBank11[0x07]; // Network identification (NID0/NID1)
bank11 uns8  ntwVRNFNZ          @ usedBank11[0x09]; // VRN of first Node in given zone
bank11 uns8  ntwCFG			    @ usedBank11[0x0A]; // Network configuration
//
bank11 uns8 memoryOffsetFrom    @ usedBank11[0x0B]; // Offset for copying buffers
bank11 uns8 memoryOffsetTo      @ usedBank11[0x0C]; // Offset for copying buffers
bank11 uns8 userStatus          @ usedBank11[0x0D]; // Register cleared by OS after power-on reset but not after other reset types
bank11 uns8 toutRF              @ usedBank11[0x0E]; // Timeout for RFRXpacket duration
bank11 uns8 RFspeed             @ usedBank11[0x0F]; // Current RF speed !!! Read Only !!!
bank11 uns8 RFpower             @ usedBank11[0x10]; // Current RF power !!! Read Only !!!
bank11 uns8 RFchannel           @ usedBank11[0x11]; // Current RF channel !!! Read Only !!!
bank11 uns8 SPIpacketLength     @ usedBank11[0x12]; // SPI packet length !!! Read Only !!!
bank11 uns8 lastRSSI            @ usedBank11[0x16]; // RSSI of last receipt !!! Read Only !!!
bank11 uns8 configFRC           @ usedBank11[0x17]; // FRC configuration
bank11 uns8 responseFRCvalue    @ usedBank11[0x18]; // FRC response user value
bank11 uns16 responseFRCvalue2B @ usedBank11[0x19]; // Two bytes FRC response user value
bank11 uns8 sysReg1             @ usedBank11[0x1B]; // System register
//
bank5 uns8 FRCextraTime			@ usedBank5[0x49];	// Additional waiting time [ticks] for FRC response
bank5 uns8 bondingMask 			@ usedBank5[0x4E];	// Bonding mask for remote bonding
bank5 uns8 bondingCounter       @ usedBank5[0x4F];  // Bonding counter for remote bonding
//
#if defined TR7xD
    bank3 TmpCfg tmpCfg         @ usedBank3[0x49];  // For internal usage only
#endif
bank3 uns8 XLPticks             @ usedBank3[0x4C];  // Number of ticks remaining to end of XLP packet transmission
bank3 uns8 memoryLimit          @ usedBank3[0x4D];  // Limit for copying buffers
//
bank0 uns8 sysReg2              @ usedBank0[0x22];  // System register
//******************************************************************************
// After getStatusSPI() in param2 there are information as below
//******************************************************************************
bit _SPIRX             		    @ param2.3;         // Something received on SPI
bit _SPICRCok          		    @ param2.4;         // Received SPICRC (last one) was OK

//******************************************************************************
// After device reset in userReg0 there are information as below
//******************************************************************************
bit _BOR             			@ userReg0.0;    	// Brown-out Reset flag
bit _POR             			@ userReg0.1;       // Power-on Reset flag
bit _RI             			@ userReg0.2;       // Reset Instruction Flag
bit _PD             			@ userReg0.3;       // Power-down flag
bit _TO          				@ userReg0.4;       // Watchdog time-out flag
bit _RMCLR        				@ userReg0.5;       // MCLR Reset flag
bit _STKUNF          			@ userReg0.6;       // Stack Underflow Reset flag
bit _STKOVF          			@ userReg0.7;       // Stack Overflow Reset flag
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

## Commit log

2016-12-26 Add a schema of prototype
    [kicad.sch]
2017-01-06 Add PCB
    [kicad.kicad_pcb, kicad.sch]
2017-01-08 Update schematic
    [kicad.kicad_pcb, kicad.sch]
2017-02-03 Update schematic of communication
2017-05-15 Update schematic of Smart socket
    [kicad.sch]

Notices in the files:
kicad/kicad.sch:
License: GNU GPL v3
